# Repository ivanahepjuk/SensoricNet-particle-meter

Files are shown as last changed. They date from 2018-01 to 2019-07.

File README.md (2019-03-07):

# SensoricNet-particle-meter

Check sensoricnet.com website [here](https://www.sensoricnet.com).

*ALL FILES IN THIS SensoricNet-Particle-Meter REPOSITORY ARE PUBLISHED UNDER GNU GENERAL PUBLIC LICENSE Version 3, 29 June 2007*

This is repo for sensoricnet, project backed by Vodafone. Nb-Iot stuff.

# Firmware
Please go to the firmware folder

# Hardware
Please go to HW folder

# Backend
Plese go to TBD

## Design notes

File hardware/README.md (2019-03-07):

## Hardware plans

Created in KiCAD 5.0.2

##### SENSORICNET mother board version 1.0

* Core MCU STM32F072RBT6 (128kB memory)
* Communication by Quectel BC-95 NbIOT modem
* NanoSIM socket
* MOLEX PicoClasp connector for ALPHASENSE OPC-N2 (or OPC-N3) particle meter sensor
* GPS module Antennova M10578-A2, external antenna 
* ATECC508A secure element with internal cryptographic support for data validation, encrypting/decrypting, secure key storage
* RESET button, MODE button, three status LED's, one GPS FIX LED
* Prepared for 6V/500mA power source, variable connector (based on boxing)
* OLED 128x64 SSD1306 BW display
* Pin description added
* Added socket for BME280, it can be placed externally - improved accuracy 

OUTER SIDE:

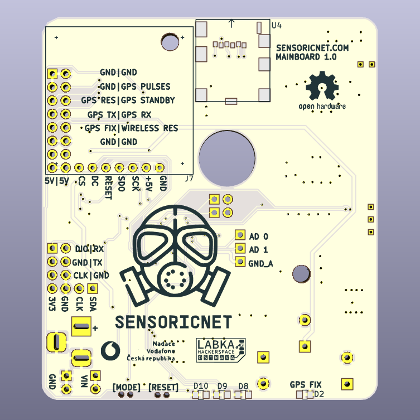
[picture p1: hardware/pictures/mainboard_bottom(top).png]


INNER SIDE:

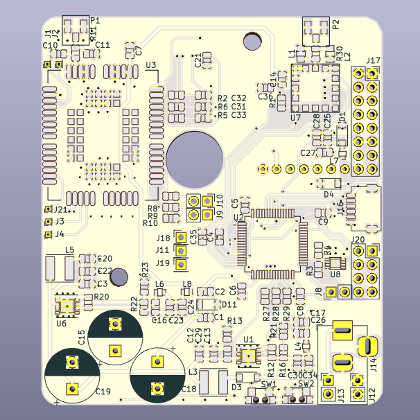
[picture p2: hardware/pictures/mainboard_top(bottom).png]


##### SENSORICNET LORAWAN shield

* Enhancement for SENSORICNET Motherboard
* Lorawan modem Microchip RN2483
* all pins form motherboard fit through this shield, possibility for adding another one

OUTER SIDE:

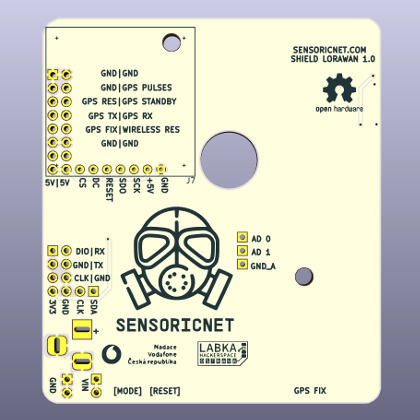
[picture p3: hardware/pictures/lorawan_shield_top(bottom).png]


INNER SIDE:

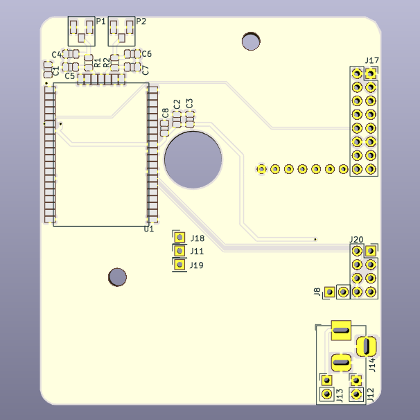
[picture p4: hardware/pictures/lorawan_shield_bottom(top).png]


##### SENSORICNET shield template
* Allows anybody to quickly develop own sensing shield for SENSORICNET
* Do you have an idea how to upgrade our sensor? Creating a shield sounds like a good way!

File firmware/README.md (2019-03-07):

# Install

##### Fedora:

(tested on Fedora release 26+)

Install openocd

```
sudo yum install openocd
sudo udevadm control -R
```

get the repo version of GNU Arm Embedded toolchains

```
sudo yum install arm-none-eabi-gdb arm-none-eabi-binutils-cs arm-none-eabi-gcc-cs arm-none-eabi-newlib
```

alternatively you can particular version of GNU Arm Embedded toolchains by

```
wget "https://armkeil.blob.core.windows.net/developer/Files/downloads/gnu-rm/6-2017q2/gcc-arm-none-eabi-6-2017-q2-update-linux.tar.bz2"
tar xvjf gcc-arm-none-eabi-6-2017-q2-update-linux.tar.bz2
```

and add path to .bash_profile

```
PATH=$PATH:/home/user/gcc-arm-none-eabi-6-2017-q2-update/bin
```

```
source .bash_profile
```

Get libopencm3

```
mkdir ~/git
cd ~/git
git clone https://github.com/libopencm3/libopencm3.git
```
checkout to used snapshot
```
git checkout f8aa36818ac57f92b68fbc7cd65767e782c5a3c8
```

and compile it

```
cd ~/git/libopencm3
make
```

Get the SensoricNet stuff

```
cd ~/git
git clone https://github.com/ivanahepjuk/SensoricNet-particle-meter.git
```

connect device, compile and flash the firmware

```
cd ~/git/SensoricNet-particle-meter/firmware/snpm/
make clean ; make flash
```

or probably the smarter way is using simple provisioning utility

- rename sensoricnet_lora_ids_example.csv file to sensoricnet_lora_ids.csv and modify it (add your data)
- compile and flash the stuff by running 

```
cd ~/git/SensoricNet-particle-meter/firmware/snpm/
./make_lora.sh <your_sensor_dev_id>
```

##### Debian 9

```
cd ~/git
git clone https://github.com/ivanahepjuk/SensoricNet-particle-meter.git
```

libopencm3 library:

```
cd SensoricNet.../firmware
git clone libopencm3
```

toolchain:

```

go to your home folder and make dedicated folder for arm toolchain:
mkdir ~/ARM_toolchain

download toolchain file into this ARM_toolchain folder:
https://developer.arm.com/open-source/gnu-toolchain/gnu-rm/downloads/6-2017-q2-update

extract it:
tar -xf <toolchain_file>

go to your home folder 
cd ~/

make a new file, name it .bash_profile
nano .bash_profile

and define path top your toolchain here (add this line with path to your toolchain files)
PATH=$PATH:/home/ia/ARM_toolchain/gcc-arm-none-eabi-6-2017-q2-update/bin

save it by pressing ctrl+x and then load it:
source ~/.bash_profile

test it by writing this into terminal:
arm-none-eabi-gcc --version

you should get this:
arm-none-eabi-gcc (GNU Tools for ARM Embedded Processors 6-2017-q2-update) 6.3.1 20170620 (release) [ARM/embedded-6-branch revision 249437]
Copyright (C) 2016 Free Software Foundation, Inc.
This is free software; see the source for copying conditions.  There is NO
warranty; not even for MERCHANTABILITY or FITNESS FOR A PARTICULAR PURPOSE.

////////////////////////////////////////////////////////////////
////////////////////////////////////////////////////////////////
////////////////////////////////////////////////////////////////

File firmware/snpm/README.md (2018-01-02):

# README

Put it into f0 example folder, libopencm3

## Board connections

| Port  | Function | Description |
| ----- | --- | --- |
| `PA9` | `(USART1_TX)`	| TTL serial output `(38400,8,N,1)` |

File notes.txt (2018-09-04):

Project layout
--------------

..
└── git
    ├── libopencm3
    └── SensoricNet-particle-meter

CPU used
--------

ARM STM32F072

GNU Arm Embedded Toolchain:
---------------------------

The GNU Arm Embedded toolchains are integrated and validated packages featuring the Arm Embedded GCC compiler,
libraries and other GNU tools necessary for bare-metal software development on devices based on the 
Arm Cortex-M and Cortex-R processors. 

  * https://developer.arm.com/open-source/gnu-toolchain/gnu-rm/downloads

Semihosting
-----------

Semihosting is a neat way to redirect STDOUT and STDIN from an embedded system to a debug window on a PC.
This allows you to output messages using printf functions without having to use/configure an RS232 or 
USB Virtual COM Port, and can also read input from the PC's keyboard via scanf functions.

  * http://www.keil.com/support/man/docs/armcc/armcc_pge1358787046598.htm
  * http://bgamari.github.io/posts/2014-10-31-semihosting.html
  * https://github.com/libopencm3/libopencm3-examples/tree/master/examples/stm32/l1/stm32l-discovery/usart-semihosting
  * https://github.com/rowol/stm32_discovery_arm_gcc/tree/master/semihosting
  * http://www.wolinlabs.com/blog/stm32f4.semihosting.html
  * http://www.openstm32.org/forumthread164#threadId798

vypadá to, že to funguje. Po přeložení a flashnutí je pořeba znovu spustit openocd

openocd -f /usr/share/openocd/scripts/interface/stlink-v2-1.cfg -f /usr/share/openocd/scripts/target/stm32f0x.cfg

a připojit se na port 4444

telnet localhost 4444

a tam zadat

arm semihosting enable
reset

určitě to půjde zautomatizovat v Makefile

POZOR! pokud se překládá s podporou semihosting (je to default), tak musí být připojený ST-LINK,
       jinak ta binárka nepoběží!!! Překlad bez semihostingu je potřeba explicitně provést pomocí

make ENABLE_SEMIHOSTING=0 flash

Alternativa je retargeting (imho presmerovani USART2 do debug konzole)

  * https://github.com/ChuckM/nucleo-retarget-example

GDB (GNU debuger)
-----------------

  * https://mcuoneclipse.com/2015/03/25/command-line-programming-and-debugging-with-gdb/
  * http://pandafruits.com/stm32_primer/stm32_primer_minimal.php

Hromadný deploying
------------------

Je potřeba si lokálně udržovat aktuální csv soubor s čidly (vzor je sensoricnet_lora_ids_example.csv).
Pak se kompilace provádí pomocí

cd ~/git/SensoricNet-particle-meter/firmware/snpm/
./make_lora.sh <your_sensor_dev_id>

////////////////////////////////
ukoly

Vyresit ID jednotlivych senzoru, tzn mozna HWID? Mozna funkci na zapis ID?

Benchmark gps?

Posilat vic zajimavych dat z quectelu. Posilat jako string, nevymyslet picoviny, easy to poslat.

Preruseni na usart, vyzkouset ale si neni jak? Jo je, ale jen pri up-linku.

//SPI connections:
GND
SCK
MOSI/SDI
MISO/SDO
SS
5V

GPS modul
---------

Sample input from module, USART2, baudrate 9600

$GPRMC,002911.261,V,,,,,0.00,0.00,060180,,,N*4C
$GPVTG,0.00,T,,M,0.00,N,0.00,K,N*32
$GPGGA,002912.261,,,,,0,0,,,M,,M,,*45
$GPGLL,,,,,002912.261,V,N*77
$GPGSA,A,1,,,,,,,,,,,,,,,*1E
$GPGSV,1,1,00*79

Popis:

$GPRMC

    Recommended minimum specific GPS/Transit data

    eg1. $GPRMC,081836,A,3751.65,S,14507.36,E,000.0,360.0,130998,011.3,E*62
    eg2. $GPRMC,225446,A,4916.45,N,12311.12,W,000.5,054.7,191194,020.3,E*68

           225446       Time of fix 22:54:46 UTC
           A            Navigation receiver warning A = OK, V = warning
           4916.45,N    Latitude 49 deg. 16.45 min North
           12311.12,W   Longitude 123 deg. 11.12 min West
           000.5        Speed over ground, Knots
           054.7        Course Made Good, True
           191194       Date of fix  19 November 1994
           020.3,E      Magnetic variation 20.3 deg East
           *68          mandatory checksum

    eg3. $GPRMC,220516,A,5133.82,N,00042.24,W,173.8,231.8,130694,004.2,W*70
            1    2    3    4    5     6    7    8      9     10  11 12

        1   220516     Time Stamp
        2   A          validity - A-ok, V-invalid
        3   5133.82    current Latitude
        4   N          North/South
        5   00042.24   current Longitude
        6   W          East/West
        7   173.8      Speed in knots
        8   231.8      True course
        9   130694     Date Stamp
        10  004.2      Variation
        11  W          East/West
        12  *70        checksum

    eg4. $GPRMC,hhmmss.ss,A,llll.ll,a,yyyyy.yy,a,x.x,x.x,ddmmyy,x.x,a*hh
    1    = UTC of position fix
    2    = Data status (V=navigation receiver warning)
    3    = Latitude of fix
    4    = N or S
    5    = Longitude of fix
    6    = E or W
    7    = Speed over ground in knots
    8    = Track made good in degrees True
    9    = UT date
    10   = Magnetic variation degrees (Easterly var. subtracts from true course)
    11   = E or W
    12   = Checksum

$GPVTG

    Track Made Good and Ground Speed.

    eg1. $GPVTG,360.0,T,348.7,M,000.0,N,000.0,K*43
    eg2. $GPVTG,054.7,T,034.4,M,005.5,N,010.2,K

           054.7,T      True track made good
           034.4,M      Magnetic track made good
           005.5,N      Ground speed, knots
           010.2,K      Ground speed, Kilometers per hour

    eg3. $GPVTG,t,T,,,s.ss,N,s.ss,K*hh
    1    = Track made good
    2    = Fixed text 'T' indicates that track made good is relative to true north
    3    = not used
    4    = not used
    5    = Speed over ground in knots
    6    = Fixed text 'N' indicates that speed over ground in in knots
    7    = Speed over ground in kilometers/hour
    8    = Fixed text 'K' indicates that speed over ground is in kilometers/hour
    9    = Checksum

    The actual track made good and speed relative to the ground.

    $--VTG,x.x,T,x.x,M,x.x,N,x.x,K
    x.x,T = Track, degrees True
    x.x,M = Track, degrees Magnetic
    x.x,N = Speed, knots
    x.x,K = Speed, Km/hr 

$GPGGA

    Global Positioning System Fix Data

    Name                      Example Data          Description
    Sentence Identifier               $GPGGA              Global Positioning System Fix Data
    Time                      170834              17:08:34 Z
    Latitude                    4124.8963, N          41d 24.8963' N or 41d 24' 54" N
    Longitude                     08151.6838, W           81d 51.6838' W or 81d 51' 41" W
    Fix Quality:
    - 0 = Invalid
    - 1 = GPS fix
    - 2 = DGPS fix                  1                 Data is from a GPS fix
    Number of Satellites              05                5 Satellites are in view
    Horizontal Dilution of Precision (HDOP)     1.5               Relative accuracy of horizontal position
    Altitude                    280.2, M            280.2 meters above mean sea level
    Height of geoid above WGS84 ellipsoid       -34.0, M            -34.0 meters
    Time since last DGPS update           blank               No last update
    DGPS reference station id             blank               No station id
    Checksum                    *75               Used by program to check for transmission errors

    Global Positioning System Fix Data. Time, position and fix related data for a GPS receiver.

    eg2. $--GGA,hhmmss.ss,llll.ll,a,yyyyy.yy,a,x,xx,x.x,x.x,M,x.x,M,x.x,xxxx

    hhmmss.ss = UTC of position
    llll.ll = latitude of position
    a = N or S
    yyyyy.yy = Longitude of position
    a = E or W
    x = GPS Quality indicator (0=no fix, 1=GPS fix, 2=Dif. GPS fix)
    xx = number of satellites in use
    x.x = horizontal dilution of precision
    x.x = Antenna altitude above mean-sea-level
    M = units of antenna altitude, meters
    x.x = Geoidal separation
    M = units of geoidal separation, meters
    x.x = Age of Differential GPS data (seconds)
    xxxx = Differential reference station ID

    eg3. $GPGGA,hhmmss.ss,llll.ll,a,yyyyy.yy,a,x,xx,x.x,x.x,M,x.x,M,x.x,xxxx*hh
    1    = UTC of Position
    2    = Latitude
    3    = N or S
    4    = Longitude
    5    = E or W
    6    = GPS quality indicator (0=invalid; 1=GPS fix; 2=Diff. GPS fix)
    7    = Number of satellites in use [not those in view]
    8    = Horizontal dilution of position
    9    = Antenna altitude above/below mean sea level (geoid)
    10   = Meters  (Antenna height unit)
    11   = Geoidal separation (Diff. between WGS-84 earth ellipsoid and
         mean sea level.  -=geoid is below WGS-84 ellipsoid)
    12   = Meters  (Units of geoidal separation)
    13   = Age in seconds since last update from diff. reference station
    14   = Diff. reference station ID#
    15   = Checksum

$GPGLL

    Geographic Position, Latitude / Longitude and time.

    eg1. $GPGLL,3751.65,S,14507.36,E*77
    eg2. $GPGLL,4916.45,N,12311.12,W,225444,A

           4916.46,N    Latitude 49 deg. 16.45 min. North
           12311.12,W   Longitude 123 deg. 11.12 min. West
           225444       Fix taken at 22:54:44 UTC
           A            Data valid

    eg3. $GPGLL,5133.81,N,00042.25,W*75
             1    2     3    4 5

        1    5133.81   Current latitude
        2    N         North/South
        3    00042.25  Current longitude
        4    W         East/West
        5    *75       checksum

    $--GLL,lll.ll,a,yyyyy.yy,a,hhmmss.ss,A llll.ll = Latitude of position

    a = N or S
    yyyyy.yy = Longitude of position
    a = E or W
    hhmmss.ss = UTC of position
    A = status: A = valid data 

$GPGSA

    GPS DOP and active satellites

    eg1. $GPGSA,A,3,,,,,,16,18,,22,24,,,3.6,2.1,2.2*3C
    eg2. $GPGSA,A,3,19,28,14,18,27,22,31,39,,,,,1.7,1.0,1.3*35

    1    = Mode:
         M=Manual, forced to operate in 2D or 3D
         A=Automatic, 3D/2D
    2    = Mode:
         1=Fix not available
         2=2D
         3=3D
    3-14 = IDs of SVs used in position fix (null for unused fields)
    15   = PDOP
    16   = HDOP
    17   = VDOP

$GPGSV

    GPS Satellites in view

    eg. $GPGSV,3,1,11,03,03,111,00,04,15,270,00,06,01,010,00,13,06,292,00*74
      $GPGSV,3,2,11,14,25,170,00,16,57,208,39,18,67,296,40,19,40,246,00*74
      $GPGSV,3,3,11,22,42,067,42,24,14,311,43,27,05,244,00,,,,*4D

      $GPGSV,1,1,13,02,02,213,,03,-3,000,,11,00,121,,14,13,172,05*67

    1    = Total number of messages of this type in this cycle
    2    = Message number
    3    = Total number of SVs in view
    4    = SV PRN number
    5    = Elevation in degrees, 90 maximum
    6    = Azimuth, degrees from true north, 000 to 359
    7    = SNR, 00-99 dB (null when not tracking)
    8-11 = Information about second SV, same as field 4-7
    12-15= Information about third SV, same as field 4-7
    16-19= Information about fourth SV, same as field 4-7

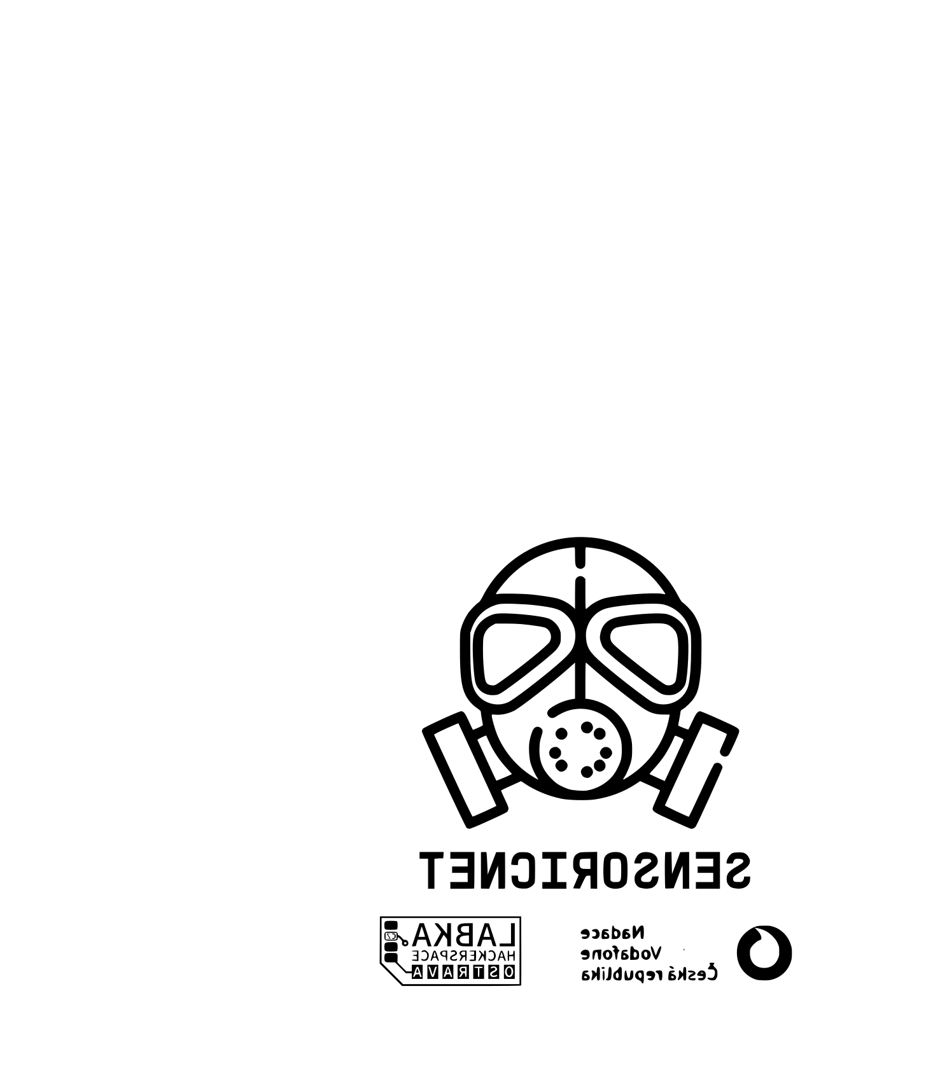
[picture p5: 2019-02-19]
hardware/footprints_and_modules/graphics/.svg2shenzhen-cache/images/F.Cu_g4502.png

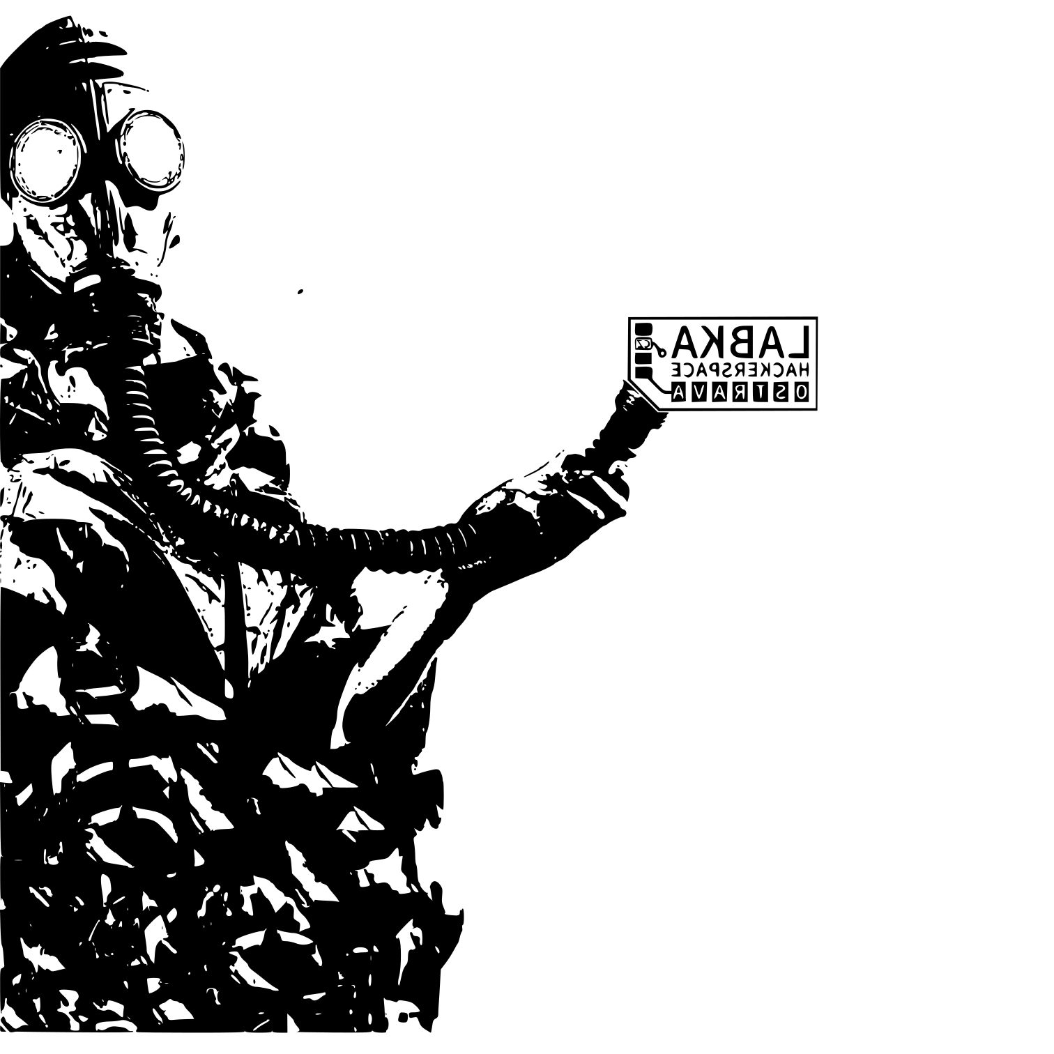
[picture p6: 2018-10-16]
hardware/footprints_and_modules/graphics/.svg2shenzhen-cache/images/F.Cu_g4633.png

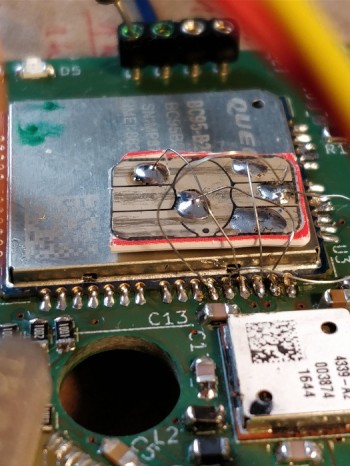
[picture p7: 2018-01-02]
Pictures/simka_resize.jpg

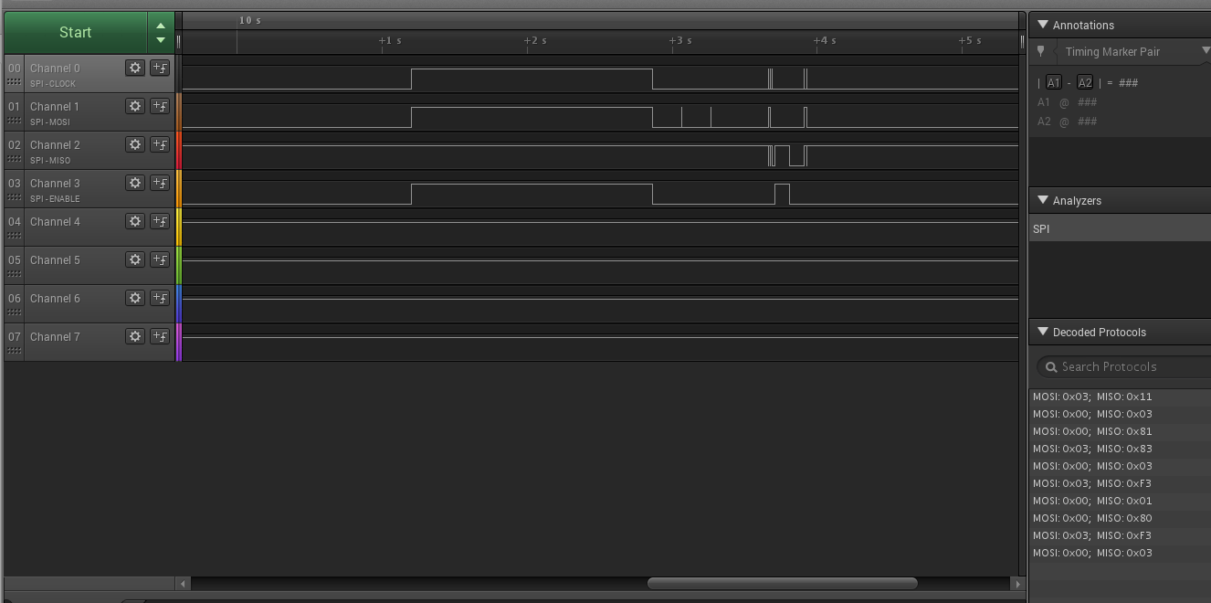
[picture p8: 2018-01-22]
firmware/communication_ok.png

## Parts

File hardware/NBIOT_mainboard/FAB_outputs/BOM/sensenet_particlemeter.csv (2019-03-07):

Id | Designator | Package | Quantity | Designation | Supplier and ref
1 | R9,R1,R8,R23,R27,R28,R29 | R_0805_2012Metric | 7 | 1k
2 | LOGO1 | PCB_artwork | 1 | LOGO
3 | U4 | nanosimmm | 1 | SIM
4 | U2 | TQFP-64_10x10mm_Pitch0.5mm | 1 | stm32f072
5 | J1,J2,J3,J4,J21 | Pin_Header_Straight_1x01_Pitch1.00mm | 5 | CONN_01X01
6 | J5,J6 | MountingHole_3.2mm_M3_DIN965 | 2 | CONN_01X01
7 | L2,L1 | SMD_0805 | 2 | DNP
8 | U3 | quectel_BC95 | 1 | QUECTEL_BC95
9 | U7 | M10578 | 1 | M10578-A2
10 | J11,J18,J19 | Pin_Header_Straight_1x01_Pitch2.54mm | 3 | CONN_01X01
11 | L4,L6,L7,L8 | R_0603 | 4 | FBMH1608HL601-T
12 | D2,D10 | SMD_0805_bottom | 2 | LED GREEN
13 | D8 | SMD_0805_bottom | 1 | LED RED
14 | D9 | SMD_0805_bottom | 1 | LED YELLOW
15 | P1,P2 | Antenna_conn | 2 | SMA_mini
16 | SW1,SW2 | edge_switch | 2 | SW_DPST
17 | C17,C25,C1,C4,C5,C6,C7,C8,C9,C12,C20,C21,C23,C36 | C_0805_2012Metric | 14 | 100n
18 | R30,R11 | R_0805_2012Metric | 2 | 0R
19 | C28,C2 | C_0805_2012Metric | 2 | 22p
20 | C26,C27,C29,C22,C24,C35 | C_0805_2012Metric | 6 | 1n
21 | C30,C16,C34 | C_0805_2012Metric | 3 | 47u
22 | U1,U6 | DFN-8-1EP_4x4mm_P0.8mm_EP2.39x2.21mm | 2 | NCP59152
23 | D1,D4 | D_SOD-123 | 2 | PTVS3V3S1UR,115
24 | C10,C11 | C_0805_2012Metric | 2 | DNP
25 | C13,C3 | C_0805_2012Metric | 2 | 22u
26 | C14 | C_0805_2012Metric | 1 | 2,2u
27 | J17 | PinSocket_2x08_P2.54mm_Vertical | 1 | Conn_02x08_Odd_Even
28 | J20 | PinSocket_2x04_P2.54mm_Vertical | 1 | Conn_02x04_Odd_Even
29 | R3,R4 | R_0805_2012Metric | 2 | 4k7
30 | U8 | DFN-8-1EP_3x2mm_P0.5mm_EP1.75x1.45mm | 1 | ATECC508A
31 | R10 | R_0805_2012Metric | 1 | 10k
32 | R12,R13,R20 | R_0805_2012Metric | 3 | 100k
33 | R16 | R_0805_2012Metric | 1 | 3k3
34 | R21 | R_0805_2012Metric | 1 | 1k1
35 | R22 | R_0805_2012Metric | 1 | 1k6
36 | C31,C32,C33 | C_0805_2012Metric | 3 | 33p
37 | R2,R5,R6 | R_0805_2012Metric | 3 | 22R
38 | D3 | D_SOD-123 | 1 | D_Schottky_ss14
39 | D11 | D_SOD-123 | 1 | SM2T3V3A
40 | J16 | pico_clasp_6_horizontal | 1 | Conn_01x06_Female
41 | L3 | L_Taiyo-Yuden_NR-50xx | 1 | 39uH
42 | L5 | L_Taiyo-Yuden_NR-50xx | 1 | 41uH
43 | J8,J9,J10 | PinHeader_1x02_P2.54mm_Vertical | 3 | Conn_02x01
44 | C18 | CP_Radial_D10.0mm_P5.00mm | 1 | 470uF
45 | C19,C15 | CP_Radial_D10.0mm_P5.00mm | 2 | 470u
46 | J7 | OLED | 1 | Conn_01x07_Female
47 | LOGO2 | OSHW-Logo2_9.8x8mm_BackSilkScreen | 1 | LOGO
48 | J12 | BarrelJack_Horizontal | 1 | Barrel_Jack_Switch
49 | J13,J14 | PinHeader_1x02_P2.54mm_Vertical | 2 | Conn_01x02_Female

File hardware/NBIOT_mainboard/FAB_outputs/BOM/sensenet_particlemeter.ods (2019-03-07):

Id | Designator | Package | Quantity | Designation | Populate | Just order | Discuss | Notes | Links
1 | R9,R1,R8,R23,R27,R28,R29 | R_0805_2012Metric | 7 | 1k | yes
2 | LOGO1 | PCB_artwork | 1 | LOGO | no
3 | U4 | nanosimmm | 1 | SIM | yes |  |  |  | https://www.tme.eu/cz/details/mx-504520-0691_c/konektory-ke-kartam/molex/504520-0691/
4 | U2 | TQFP-64_10x10mm_Pitch0.5mm | 1 | stm32f072 | yes |  |  | STM32F072RBT6 | https://www.arrow.com/en/products/stm32f072rbt6/stmicroelectronics
5 | J1,J2,J3,J4,J21 | Pin_Header_Straight_1x01_Pitch1.00mm | 5 | CONN_01X01 | no | yes*
6 | J5,J6 | MountingHole_3.2mm_M3_DIN965 | 2 | CONN_01X01 | no
7 | L2,L1 | SMD_0805 | 2 | DNP | no
8 | U3 | quectel_BC95 | 1 | QUECTEL_BC95 | yes |  |  |  | https://www.soselectronic.cz/products/quectel/bc95-b20-bc95-b20hb-02-std-234632
9 | U7 | M10578 | 1 | M10578-A2 | yes |  |  |  | https://www.arrow.com/en/products/m10578-a2/antenova
10 | J11,J18,J19 | Pin_Header_Straight_1x01_Pitch2.54mm | 3 | CONN_01X01 |  | yes*
11 | L4,L6,L7,L8 | R_0603 | 4 | FBMH1608HL601-T | yes |  |  |  | https://www.arrow.com/en/products/fbmh1608hl601-t/taiyo-yuden
12 | D2,D10 | SMD_0805_bottom | 2 | LED GREEN | yes |  | x | please choose
13 | D8 | SMD_0805_bottom | 1 | LED RED | yes |  | x | please choose
14 | D9 | SMD_0805_bottom | 1 | LED YELLOW | yes |  | x | please choose
15 | P1,P2 | Antenna_conn | 2 | SMA_mini | yes |  | x |  | ???
16 | SW1,SW2 | edge_switch | 2 | SW_DPST | yes |  | x |  | ???
17 | C17,C25,C1,C4,C5,C6,C7,C8,C9,C12,C20,C21,C23,C36 | C_0805_2012Metric | 14 | 100n | yes |  |  |  | 6.3V
18 | R30,R11 | R_0805_2012Metric | 2 | 0R | yes
19 | C28,C2 | C_0805_2012Metric | 2 | 22p | yes |  |  |  | 6.3V
20 | C26,C27,C29,C22,C24,C35 | C_0805_2012Metric | 6 | 1n | yes |  |  |  | 6.3V
21 | C30,C16,C34 | C_0805_2012Metric | 3 | 47u | yes |  |  |  | 6.3V
22 | U1,U6 | DFN-8-1EP_4x4mm_P0.8mm_EP2.39x2.21mm | 2 | NCP59152 | yes |  |  | NCP59152MNADJTYG
23 | D1,D4 | D_SOD-123 | 2 | PTVS3V3S1UR,115 | yes |  |  |  | https://www.arrow.com/en/products/ptvs3v3s1ur115/nexperia
24 | C10,C11 | C_0805_2012Metric | 2 | DNP | no
25 | C13,C3 | C_0805_2012Metric | 2 | 22u | yes |  |  |  | 6.3V
26 | C14 | C_0805_2012Metric | 1 | 2,2u | yes |  |  |  | 6.3V
27 | J17 | PinSocket_2x08_P2.54mm_Vertical | 1 | Conn_02x08_Odd_Even |  | yes*
28 | J20 | PinSocket_2x04_P2.54mm_Vertical | 1 | Conn_02x04_Odd_Even |  | yes*
29 | R3,R4 | R_0805_2012Metric | 2 | 4k7 | yes
30 | U8 | DFN-8-1EP_3x2mm_P0.5mm_EP1.75x1.45mm | 1 | ATECC508A | yes |  |  |  | https://www.arrow.com/en/products/atecc608a-mahda-s/microchip-technology
31 | R10 | R_0805_2012Metric | 1 | 10k | yes
32 | R12,R13,R20 | R_0805_2012Metric | 3 | 100k | yes
33 | R16 | R_0805_2012Metric | 1 | 3k3 | yes
34 | R21 | R_0805_2012Metric | 1 | 1k1 | yes
35 | R22 | R_0805_2012Metric | 1 | 1k6 | yes
36 | C31,C32,C33 | C_0805_2012Metric | 3 | 33p | yes |  |  | 6.3V
37 | R2,R5,R6 | R_0805_2012Metric | 3 | 22R | yes
38 | D3 | D_SOD-123 | 1 | D_Schottky_ss14 | yes |  |  |  | https://www.arrow.com/en/products/pmeg4010eh115/nexperia
39 | D11 | D_SOD-123 | 1 | SM2T3V3A | yes |  |  |  | https://www.arrow.com/en/products/sm2t3v3a/stmicroelectronics
40 | J16 | pico_clasp_6_horizontal | 1 | Conn_01x06_Female | yes |  |  |  | https://www.arrow.com/en/products/5015680607/molex
41 | L3 | L_Taiyo-Yuden_NR-50xx | 1 | 39uH
42 | L5 | L_Taiyo-Yuden_NR-50xx | 1 | 41uH
43 | J8,J9,J10 | PinHeader_1x02_P2.54mm_Vertical | 3 | Conn_02x01 |  | yes*
44 | C18 | CP_Radial_D10.0mm_P5.00mm | 1 | 470uF | no | yes
45 | C19,C15 | CP_Radial_D10.0mm_P5.00mm | 2 | 470u | no | yes |  |  | https://www.arrow.com/en/products/ece-a0jn471x/panasonic
46 | J7 | OLED | 1 | Conn_01x07_Female | no
47 | LOGO2 | OSHW-Logo2_9.8x8mm_BackSilkScreen | 1 | LOGO | no
48 | J12 | BarrelJack_Horizontal | 1 | Barrel_Jack_Switch | yes |  | x |  | ???
49 | J13,J14 | PinHeader_1x02_P2.54mm_Vertical | 2 | Conn_01x02_Female |  | yes*
 |  |  | Another orders for each board:
 |  | Part | amount per one board: | note | Link
 |  | lte antenna check | 1 |  | https://www.arrow.com/en/products/srfl026-150/antenova
 |  | GPS antenna | 1 |  | https://www.arrow.com/en/products/sr4g031-150/antenova
 |  | wire molex | 1 | Connecting wire MOLEX s.n. 15133-0601 [100mm] | https://cz.mouser.com/ProductDetail/Molex/15133-0601?qs=jFK2DQXLaBwzzgKQ6LYJrw%3D%3D
 |  | distancni sloupek M3 | 2 | vnitrni zavit 4mm, vyska sloupku 5mm, vnejsi zavit 5mm
 |  | distancni sloupek M3 | 2 | vnitrni zavit 4mm, vyska sloupku 12mm, vnejsi zavit 5mm

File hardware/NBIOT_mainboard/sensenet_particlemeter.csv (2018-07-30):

Id | Designator | Package | Quantity | Designation | Supplier and ref
1 | P4 | USB_Micro-B | 1 | USB_B
2 | U2 | TQFP-64_10x10mm_Pitch0.5mm | 1 | stm32f072
3 | BT1 | BAT-CR2032_bottom | 1 | Battery_Cell
4 | C3,C6,C9,C13,C4,C8 | SMD_0805 | 6 | C
5 | C5,C7,C21,C25 | SMD_0805 | 4 | 100n
6 | C10,C11 | SMD_0805 | 2 | NC
7 | C14 | SMD_0805 | 1 | 2,2u
8 | C23 | SMD_0805 | 1 | 10u
9 | C24 | SMD_0805 | 1 | 220n
10 | D1 | D_SOD-123 | 1 | D_Schottky
11 | D2,D4,D7,D8,D9,D10 | SMD_0805 | 6 | LED
12 | D3 | D_SOD-123 | 1 | D_Schottky_ss14
13 | J1,J2,J3,J4,J21 | Pin_Header_Straight_1x01_Pitch1.00mm | 5 | CONN_01X01
14 | J5,J6 | MountingHole_3.2mm_M3_DIN965 | 2 | CONN_01X01
15 | J13 | BARREL_JACK | 1 | BARREL_JACK
16 | L2,L1 | SMD_0805 | 2 | L
17 | P1,P2 | Antenna_conn | 2 | SMA_mini
18 | R1,R17,R18,R27,R28,R29 | SMD_0805 | 6 | R
19 | R2,R4,R5 | SMD_0805 | 3 | 4.7k
20 | R3,R26 | SMD_0805 | 2 | 5k6
21 | R6 | SMD_0805 | 1 | 22k
22 | R7,R10,R14 | SMD_0805 | 3 | 10k
23 | R8,R9 | SMD_0805 | 2 | 1k
24 | U3 | quectel_BC95 | 1 | QUECTEL_BC95
25 | U7 | M10578 | 1 | M10578-A2
26 | U10 | BME280 | 1 | bme280_barebone
27 | J11,J17,J18,J19,J20 | Pin_Header_Straight_1x01_Pitch2.54mm | 5 | CONN_01X01
28 | SJ16 | solder_jumper | 1 | solder_jumper
29 | Y1 | Crystal_SMD_5032-2pin_5.0x3.2mm | 1 | 8MHz
30 | C1,C2 | SMD_0805 | 2 | 4.3p
31 | C12 | SMD_0805 | 1 | 510pF
32 | C15 | SMD_0805 | 1 | 1u
33 | R12,R19 | SMD_0805 | 2 | 0R33
34 | R13,R20,R21,R24 | SMD_0805 | 4 | tbd
35 | R15 | SMD_0805 | 1 | 27k
36 | R16 | SMD_0805 | 1 | 9.1k
37 | U1,U6 | SOIC-8_3.9x4.9mm_Pitch1.27mm | 2 | MC33063
38 | U5 | SOT-23-5 | 1 | CAT24C02
39 | Q1 | SOT-23 | 1 | Q_NMOS_GSD
40 | U4 | nanosimmm | 1 | SIM
41 | R11 | SMD_0805 | 1 | 0R
42 | C16 | SMD_0805 | 1 | 352pF
43 | R22 | SMD_0805 | 1 | 18k
44 | R23 | SMD_0805 | 1 | 11k
45 | R25,R30 | SMD_0805 | 2 | 0R1
46 | L3 | Inductor_Taiyo-Yuden_NR-50xx | 1 | 39uH
47 | L4,L6 | SMD_0805 | 2 | 1uH
48 | L5 | Inductor_Taiyo-Yuden_NR-50xx | 1 | 41uH
49 | D5,D6 | SOD-123 | 2 | 1N5819
50 | C17,C19 | C_Radial_D10_L16_P5_bottom | 2 | 1000u
51 | C18 | C_Radial_D6.3_L11.2_P2.5_bottom | 1 | 470uF
52 | P3 | Pin_Header_Straight_2x12 | 1 | CONN_02X12
53 | SW2 | DIP-6_W7.62mm | 1 | SW_DIP_x03
54 | SW1,SW3 | edge_switch | 2 | SW_DPST
55 |  | drawing | 1

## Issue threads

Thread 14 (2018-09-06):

Zvýšit přesnost přenášených GPS souřadnic

dron23, 2018-09-06:
GPS souřadnice jsou enkodováním do cayenne lpp oříznuty na 4 desetinná místa. GPS ale vrací 6. Workaround je naznačen v kapitole "4.3. Full scale GPS Payload" v http://community.mydevices.com/t/cayenne-lpp-2-0/7510. Oprava se bude muset ud2lat i v dron23/SensoricNet-udp#2.

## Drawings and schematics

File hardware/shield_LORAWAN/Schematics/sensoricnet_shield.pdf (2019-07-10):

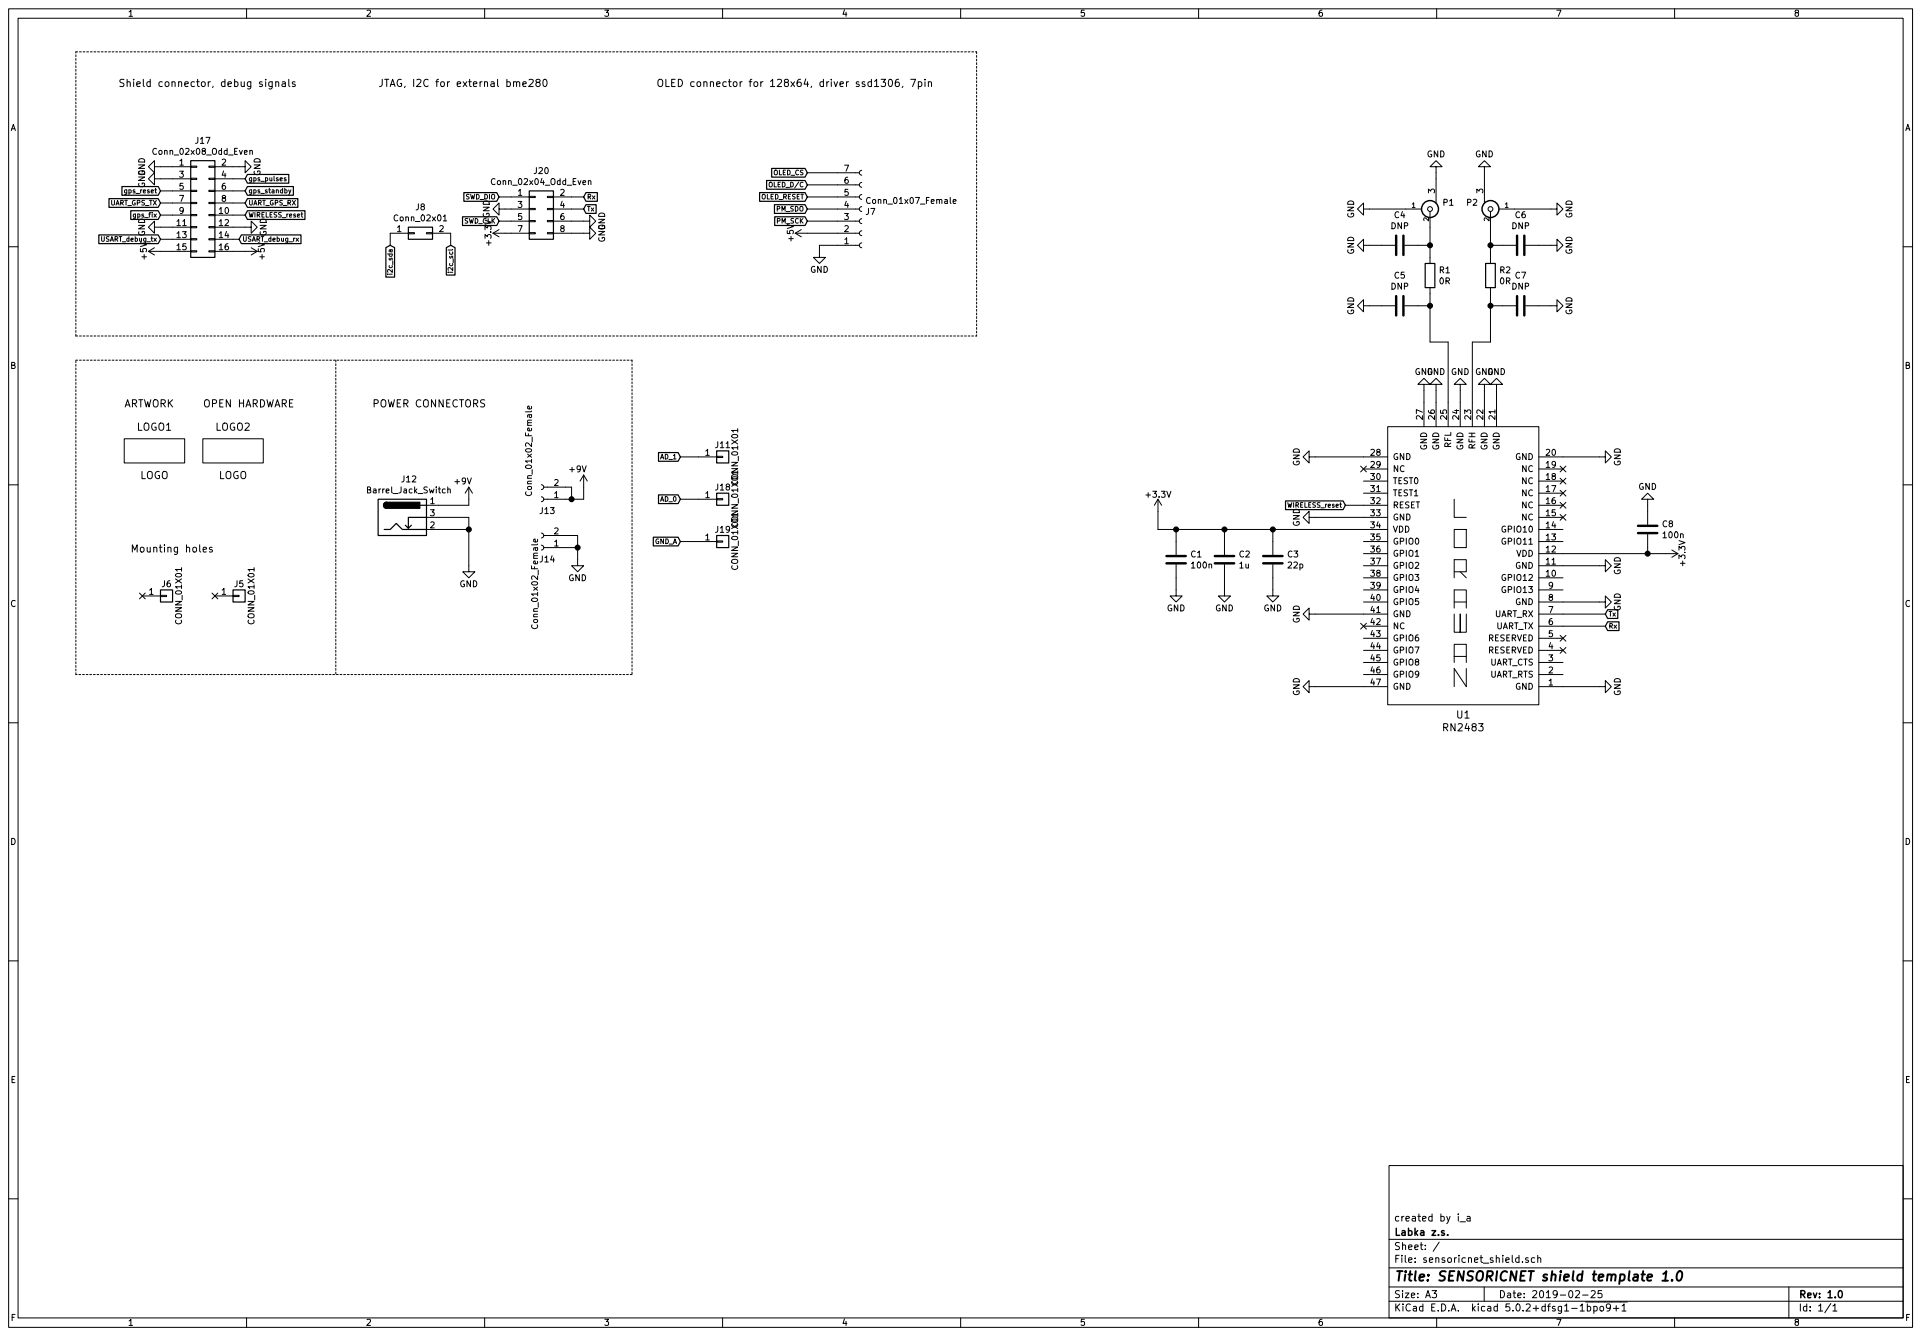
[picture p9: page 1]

2 3 P2 GND GND GND GND GNDGND GND GNDGND GND GND GND GND +3.3V WIRELESS_reset Rx Tx

C4 DNP C5 DNP GND GND

File: sensoricnet_shield.sch Sheet: / Labka z.s. created by i_a

Id: 1/1 Title: SENSORICNET shield template 1.0

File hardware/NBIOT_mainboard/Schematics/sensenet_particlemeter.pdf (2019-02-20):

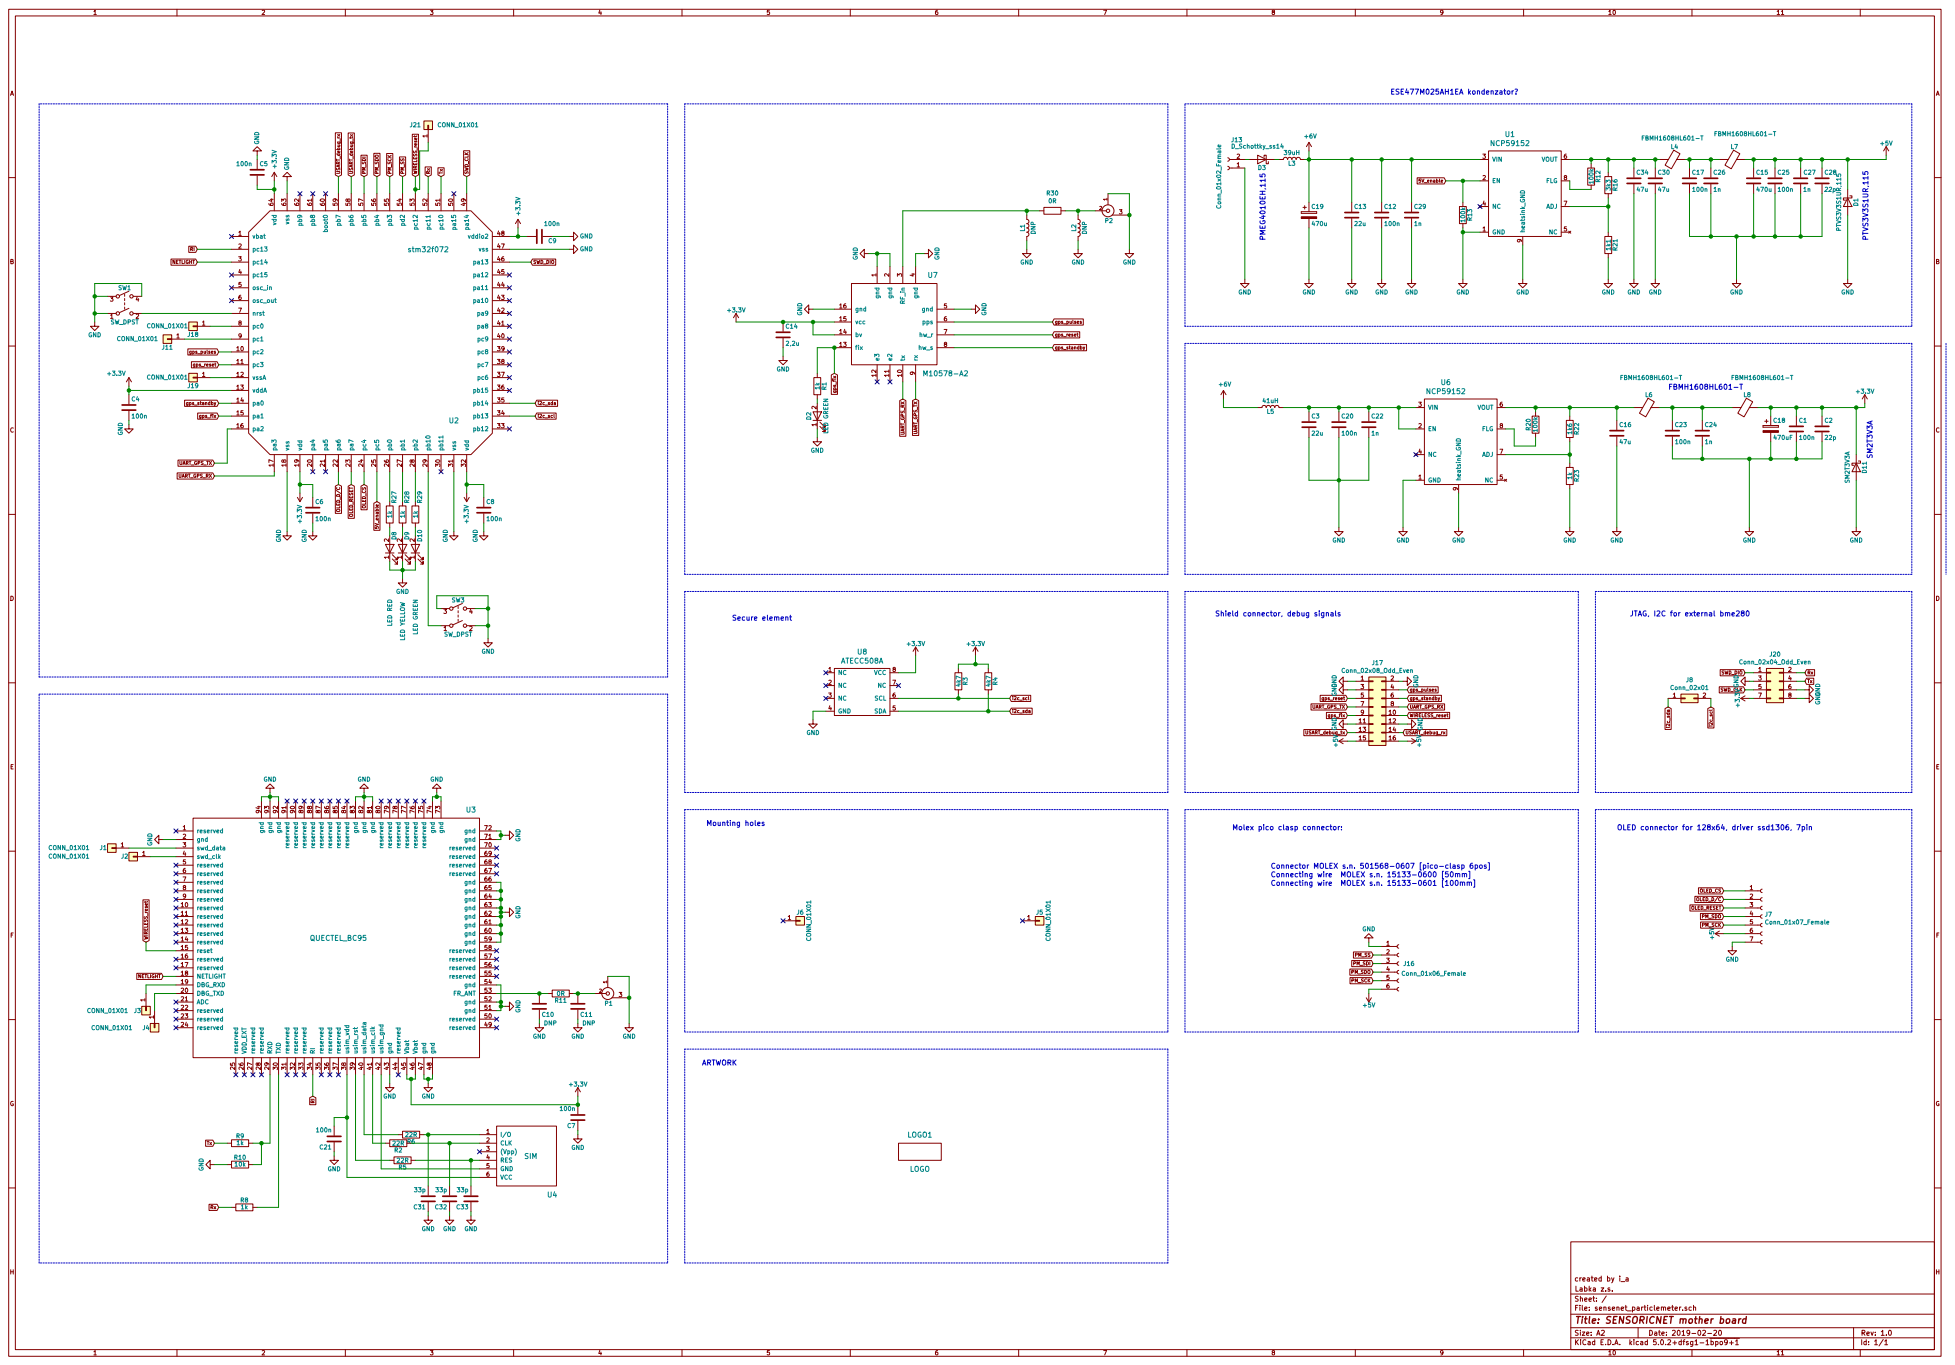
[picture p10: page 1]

1 2 D2 LED GREEN 1kR1 GND GND GND GND GND

vcc 15
fix 13
1n GND Connector MOLEX s.n. 501568-0607 [pico-clasp 6pos]

File: sensenet_particlemeter.sch Sheet: / Labka z.s. created by i_a

Id: 1/1 Title: SENSORICNET mother board

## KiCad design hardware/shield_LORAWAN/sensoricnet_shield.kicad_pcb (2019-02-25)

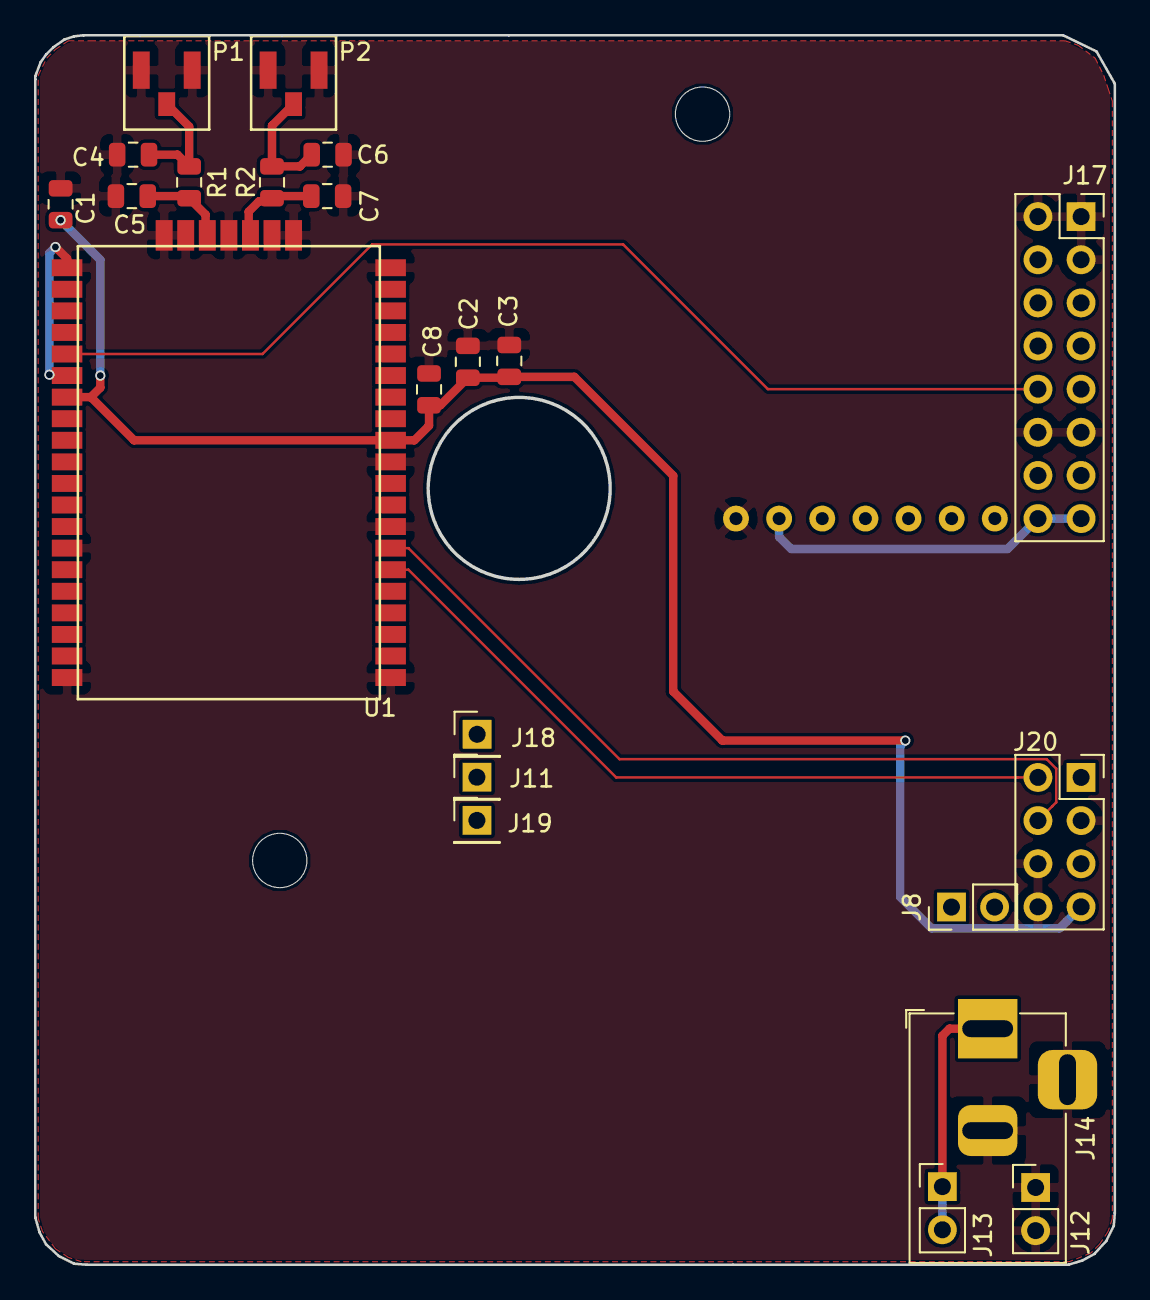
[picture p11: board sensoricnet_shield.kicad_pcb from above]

Board: 2 copper layers, 63.6 x 72.4 mm, 27 parts (0 on the bottom side), 11 nets.

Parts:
C1, C8: 100n; C_0805_2012Metric
C2: 1u; C_0805_2012Metric
C3: 22p; C_0805_2012Metric
C4, C5, C6, C7: DNP; C_0805_2012Metric
J5, J6: CONN_01X01; MountingHole_3.2mm_M3_DIN965
J7: Conn_01x07_Female; OLED
J8: Conn_02x01; PinHeader_1x02_P2.54mm_Vertical
J11, J18, J19: CONN_01X01; PinHeader_1x01_P2.54mm_Vertical
J12: Barrel_Jack_Switch; BarrelJack_Horizontal
J13, J14: Conn_01x02_Female; PinHeader_1x02_P2.54mm_Vertical
J17: Conn_02x08_Odd_Even; PinSocket_2x08_P2.54mm_Vertical
J20: Conn_02x04_Odd_Even; PinSocket_2x04_P2.54mm_Vertical
LOGO1: LOGO; PCB_artwork
LOGO2: LOGO; OSHW-Logo2_9.8x8mm_BackSilkScreen
P1, P2: SMA_mini; Antenna_conn
R1, R2: 0R; R_0805_2012Metric
U1: RN2483; RN2483_top

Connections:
+3V3: C1.1, C2.1, C3.1, C8.2, J20.7, U1.12, U1.34
+5V: J7.2, J17.15, J17.16
+9V: J12.1, J13.1, J13.2
GND: C1.2, C2.2, C3.2, C4.1, C5.1, C6.1, C7.1, C8.1, J7.1, J12.2, J12.3, J14.1, J14.2, J17.1, J17.2, J17.3, J17.11, J17.12, J20.3, J20.6, J20.8, P1.1, P1.3, P2.1, P2.3, U1.1, U1.8, U1.11, U1.20, U1.21, U1.22, U1.24, U1.26, U1.27, U1.28, U1.33, U1.41, U1.47
unnamed: C4.2, P1.2, R1.1
unnamed: C5.2, R1.2, U1.25
unnamed: C6.2, P2.2, R2.1
unnamed: C7.2, R2.2, U1.23
Rx: J20.2, U1.6
Tx: J20.4, U1.7
WIRELESS_reset: J17.10, U1.32

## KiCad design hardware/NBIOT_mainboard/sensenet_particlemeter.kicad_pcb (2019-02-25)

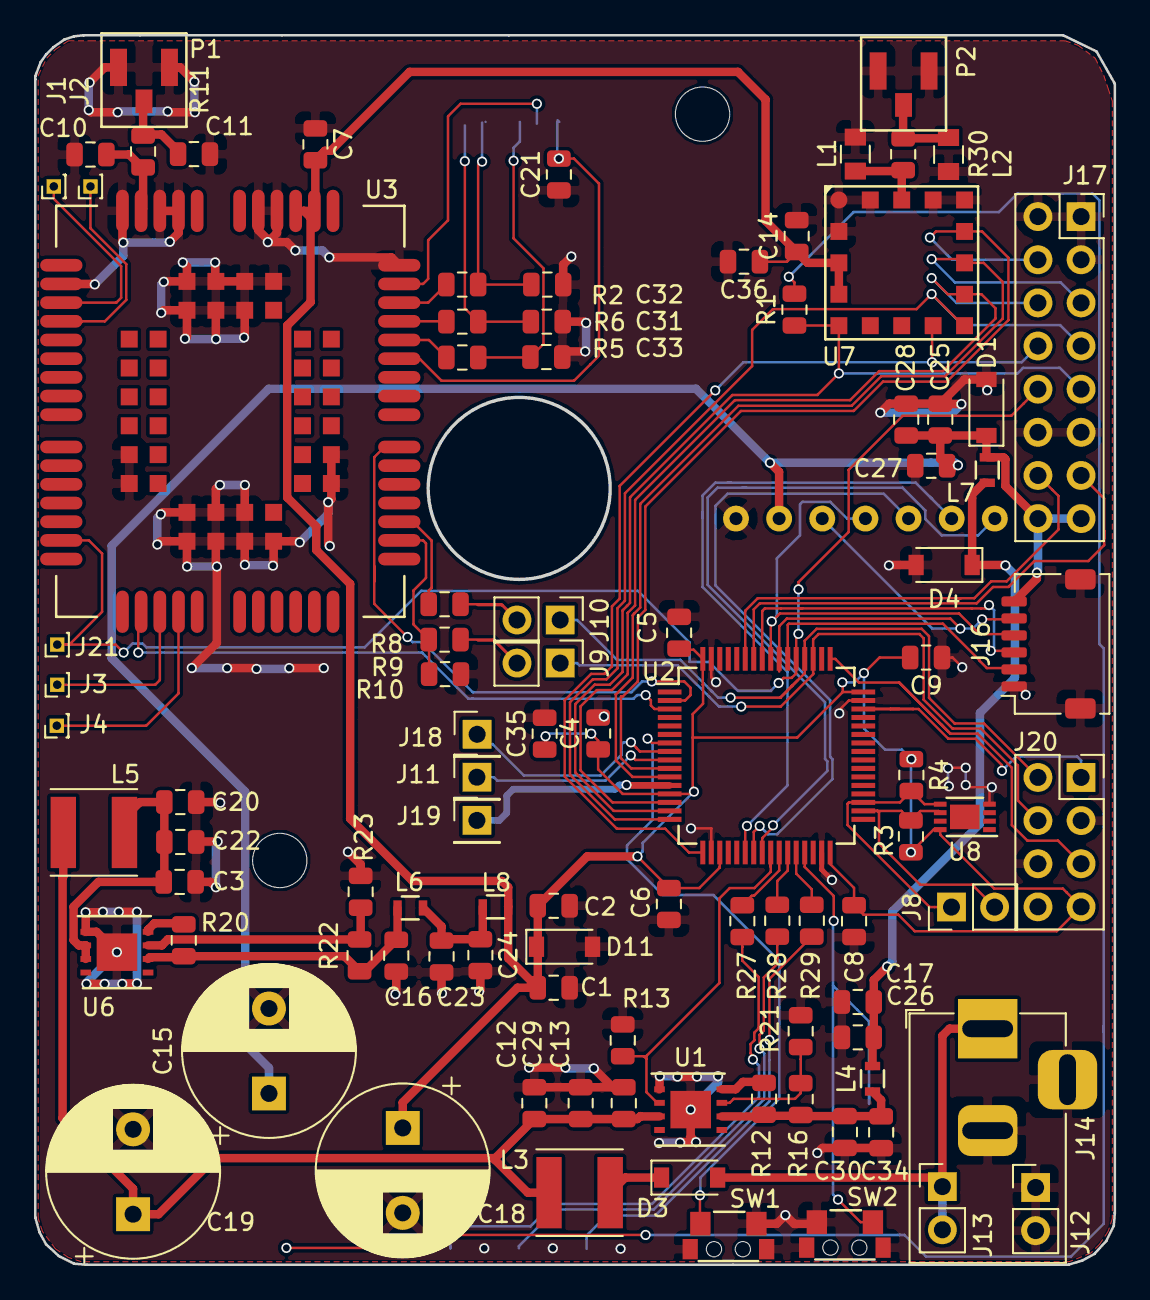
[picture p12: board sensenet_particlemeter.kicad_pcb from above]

Board: 2 copper layers, 63.6 x 72.4 mm, 106 parts (0 on the bottom side), 72 nets.

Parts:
C1, C4, C5, C6, C7, C8, C9, C12, C17, C20, C21, C23, C25, C36: 100n; C_0805_2012Metric
C2, C28: 22p; C_0805_2012Metric
C3, C13: 22u; C_0805_2012Metric
C10, C11: DNP; C_0805_2012Metric
C14: 2,2u; C_0805_2012Metric
C15, C19: 470u; CP_Radial_D10.0mm_P5.00mm
C16, C30, C34: 47u; C_0805_2012Metric
C18: 470uF; CP_Radial_D10.0mm_P5.00mm
C22, C24, C26, C27, C29, C35: 1n; C_0805_2012Metric
C31, C32, C33: 33p; C_0805_2012Metric
D1, D4: PTVS3V3S1UR,115; D_SOD-123
D2, D10: LED GREEN; SMD_0805_bottom
D3: D_Schottky_ss14; D_SOD-123
D8: LED RED; SMD_0805_bottom
D9: LED YELLOW; SMD_0805_bottom
D11: SM2T3V3A; D_SOD-123
J1, J2, J3, J4, J21: CONN_01X01; Pin_Header_Straight_1x01_Pitch1.00mm
J5, J6: CONN_01X01; MountingHole_3.2mm_M3_DIN965
J7: Conn_01x07_Female; OLED
J8, J9, J10: Conn_02x01; PinHeader_1x02_P2.54mm_Vertical
J11, J18, J19: CONN_01X01; Pin_Header_Straight_1x01_Pitch2.54mm
J12: Barrel_Jack_Switch; BarrelJack_Horizontal
J13, J14: Conn_01x02_Female; PinHeader_1x02_P2.54mm_Vertical
J16: Conn_01x06_Female; pico_clasp_6_horizontal
J17: Conn_02x08_Odd_Even; PinSocket_2x08_P2.54mm_Vertical
J20: Conn_02x04_Odd_Even; PinSocket_2x04_P2.54mm_Vertical
L1, L2: DNP; SMD_0805
L3: 39uH; L_Taiyo-Yuden_NR-50xx
L4, L6, L7, L8: FBMH1608HL601-T; R_0603
L5: 41uH; L_Taiyo-Yuden_NR-50xx
LOGO1: LOGO; PCB_artwork
LOGO2: LOGO; OSHW-Logo2_9.8x8mm_BackSilkScreen
P1, P2: SMA_mini; Antenna_conn
R1, R8, R9, R23, R27, R28, R29: 1k; R_0805_2012Metric
R2, R5, R6: 22R; R_0805_2012Metric
R3, R4: 4k7; R_0805_2012Metric
R10: 10k; R_0805_2012Metric
R11, R30: 0R; R_0805_2012Metric
R12, R13, R20: 100k; R_0805_2012Metric
R16: 3k3; R_0805_2012Metric
R21: 1k1; R_0805_2012Metric
R22: 1k6; R_0805_2012Metric
SW1, SW2: SW_DPST; edge_switch
U1, U6: NCP59152; DFN-8-1EP_4x4mm_P0.8mm_EP2.39x2.21mm
U2: stm32f072; TQFP-64_10x10mm_Pitch0.5mm
U3: QUECTEL_BC95; quectel_BC95
U4: SIM; nanosimmm
U7: M10578-A2; M10578
U8: ATECC508A; DFN-8-1EP_3x2mm_P0.5mm_EP1.75x1.45mm

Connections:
5V_enable: R13.1, U1.2, U2.25
+3V3: C1.1, C2.1, C4.1, C5.2, C6.1, C7.2, C8.1, C9.2, C14.1, C18.1, C35.1, C36.1, D11.1, J20.7, L8.1, R3.1, R4.1, U2.13, U2.19, U2.32, U2.48, U2.64, U3.45, U3.46, U7.14, U7.15, U8.8
+5V: C15.1, C25.1, C27.1, C28.1, D1.1, J7.2, J16.6, J17.15, J17.16, L7.1
+6V: C12.1, C13.1, C19.1, C29.1, L3.2, L5.1, U1.3
+9V: D3.2, J12.1, J13.1, J13.2
GND: C1.2, C2.2, C3.2, C4.2, C5.1, C6.2, C7.1, C8.2, C9.1, C10.1, C11.1, C12.2, C13.2, C14.2, C15.2, C16.2, C17.2, C18.2, C19.2, C20.2, C21.1, C22.2, C23.2, C24.2, C25.2, C26.2, C27.2, C28.2, C29.2, C30.2, C31.1, C32.1, C33.1, C34.2, C35.2, C36.2, D1.2, D2.1, D4.2, D8.1, D9.1, D10.1, D11.2, J7.1, J12.2, J12.3, J14.1, J14.2, J16.1, J17.1, J17.2, J17.3, J17.11, J17.12, J20.3, J20.6, J20.8, L1.2, L2.2, P1.1, P1.3, P2.1, P2.3, R10.1, R13.2, R21.2, R23.2, SW1.1, SW1.3, SW1.4, SW2.2, SW2.3, SW2.4, U1.1, U1.9, U2.18, U2.31, U2.47, U2.63, U3.2, U3.43, U3.47, U3.48, U3.51, U3.52, U3.54, U3.59, U3.60, U3.61, U3.62, U3.63, U3.64, U3.65, U3.66, U3.71, U3.72, U3.73, U3.74, U3.81, U3.82, U3.83, U3.92, U3.93, U3.94, U6.1, U6.9, U7.1, U7.2, U7.4, U7.5, U7.16, U8.4
NETLIGHT: U2.3, U3.18
unnamed: C10.2, R11.2, U3.53
unnamed: C11.2, P1.2, R11.1
unnamed: C16.1, L6.2, R20.2, R22.1, U6.6
unnamed: C17.1, C26.1, D4.1, L4.1, L7.2
unnamed: C3.1, C20.1, C22.1, L5.2, U6.2, U6.3
unnamed: C21.2, U3.38, U4.6
unnamed: C23.1, C24.1, L6.1, L8.2
unnamed: C30.1, C34.1, L4.2, R12.1, R16.1, U1.6
unnamed: C31.2, R6.1, U4.1
unnamed: C32.2, R2.1, U4.2
unnamed: C33.2, R5.1, U4.4
unnamed: D2.2, R1.2
unnamed: D3.1, L3.1
unnamed: D8.2, R27.2
unnamed: D9.2, R28.2
unnamed: D10.2, R29.2
unnamed: J1.1, U3.3
unnamed: J2.1, U3.4
unnamed: J3.1, U3.19
unnamed: J4.1, U3.20
unnamed: J9.2, R9.1
unnamed: J10.2, R8.1
unnamed: J11.1, U2.9
unnamed: J18.1, U2.8
unnamed: J19.1, U2.12
unnamed: L1.1, R30.2, U7.3
unnamed: L2.1, P2.2, R30.1
unnamed: R2.2, U3.41
unnamed: R5.2, U3.39
unnamed: R6.2, U3.40
unnamed: R8.2, U3.30
unnamed: R9.2, R10.2, U3.29
unnamed: R12.2, U1.8
unnamed: R16.2, R21.1, U1.7
unnamed: R20.1, U6.8
unnamed: R22.2, R23.1, U6.7
unnamed: R27.1, U2.26
unnamed: R28.1, U2.27
unnamed: R29.1, U2.28
unnamed: SW1.2, U2.7
unnamed: SW2.1, U2.29
unnamed: U3.42, U4.5
OLED_CS: J7.7, U2.24
OLED_D/C: J7.6, U2.22
OLED_RESET: J7.5, U2.23
PM_SCK: J7.3, J16.5, U2.55
PM_SDI: J16.3, U2.57
PM_SDO: J7.4, J16.4, U2.56
PM_SS: J16.2, U2.54
RI: U2.2, U3.34
Rx: J10.1, J20.2, U2.52
SWD_CLK: J20.5, U2.49
SWD_DIO: J20.1, U2.46
Tx: J9.1, J20.4, U2.51
UART_GPS_RX: J17.8, U2.17, U7.10
UART_GPS_TX: J17.7, U2.16, U7.9
USART_debug_rx: J17.14, U2.59
USART_debug_tx: J17.13, U2.58
WIRELESS_reset: J17.10, J21.1, U2.53, U3.15
gps_fix: J17.9, R1.1, U2.15, U7.13
gps_pulses: J17.4, U2.10, U7.6
gps_reset: J17.5, U2.11, U7.7
gps_standby: J17.6, U2.14, U7.8
i2c_scl: J8.2, R3.2, U2.34, U8.6
i2c_sda: J8.1, R4.2, U2.35, U8.5

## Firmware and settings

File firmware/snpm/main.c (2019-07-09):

/*
 * This file is part of the SenoricNet project, https://sensoricnet.cz
 *
 * Copyright (C) 2017 Pavel Polach <ivanahepjuk@gmail.com>
 *
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
 * You should have received a copy of the GNU Lesser General Public License
 * along with this library.  If not, see <http://www.gnu.org/licenses/>.
 */

#include "main.h"

//debug
int cykly = 0;
char cykly_str[10];

int frame_counter = 0;

/* For semihosting on newlib */
//extern void initialise_monitor_handles(void);

//Global variables for burst register reading, bme280
int32_t t_fine;
uint8_t comp_data[26];	//used for readings of compensation data
uint8_t burst_read_data[8] = {0};	//in loop measured data readed into this

// gps global variables
char gps_rx_buffer[255] = {0};
uint8_t gps_rx_buffer_pointer = 0;
char gps_utc_time[10] = {0};
char gps_latitude[9] = {0};
char gps_latitude_ns[1] = {0};
char gps_longitude[10] = {0};
char gps_longitude_ew[1] = {0};
char gps_quality_indicator[1] = {0};
char gps_altitude[8] = {0};
float wgs_latitude = 0.0;
float wgs_longitude = 0.0;
float altitude = 0.0;

// measured values
float temp = 0;
float press = 0;
float hum = 0;
float pm1 = 0;
float pm2_5 = 0;
float pm10 = 0;

//nbiot BC-95 signal data //signal strength, bit error rate
int csq[2] = {0}; //signal strength, bit error rate
int nuestats[14] = {0}; //signal power, total power, tx power, tx time, rx time, cell ID, DL MCS, UL MCS, DCI MCS, ECL, SNR, EARFCN, PCI, RSRQ


// Global variables for compensation functions, bme280:
// temperature
uint16_t dig_T1;
int16_t dig_T2, dig_T3;
// pressure
uint16_t dig_P1;
int16_t dig_P2, dig_P3, dig_P4, dig_P5, dig_P6, dig_P7, dig_P8, dig_P9;
// humidity
uint8_t dig_H1, dig_H3;
int16_t dig_H2, dig_H4, dig_H5;
int8_t dig_H6;

// dev_id
char ID[11] = {DEV_ID};
char id_decoded[23]={0};

// Global variables for burst register reading, for OPC-N2
uint8_t histogram_buffer[62];	//whole dataset of opc readed into this
uint8_t pm_values_buffer[12] = {0};	//only pm data





/********************************************************************************************
 *
 * MAIN
 *
 ********************************************************************************************/


int main(void)
{
  clock_setup();
  //systick_setup(250);//250ms tick = 500ms period = 2Hz
//  moje_iwdg_setup();
  gpio_setup();
//  usart_setup();
  i2c_setup();

while(1) {
led_flash(3, 3, 20000);
  //BME280_init();
  atecWake();
  atec();
  wait(2000000);
}
  moje_iwdg_reset();

  wait(SEC*3);
  gpio_set(GPIOD, GPIO2); //SS Log 1
  gpio_clear(GPIOD, GPIO2); //SS Log 0
  gpio_set(GPIOD, GPIO2); //SS Log 1

  debug_usart_send("Welcome to SensoricNet particlemeter");
  #if DEVICE_TYPE == NBIOT
    debug_usart_send("device type is NBIoT");
  #endif
  moje_iwdg_reset();
  particlemeter_power_cycle();
  spi_setup();
  debug_usart_send("tady");
  #if BME280 == 1
    BME280_init();
  #endif
  led_flash(1, 3, 20000);
  nbiot_reset();
  led_flash(1, 3, 200000);
	// semihosting - stdio po debug konzoli, inicializace
	/*
	#if defined(ENABLE_SEMIHOSTING) && (ENABLE_SEMIHOSTING)
		initialise_monitor_handles();
		setbuf(stdout, NULL);
	#endif
	*/
  struct CayenneLPP *lpp;
  unsigned char *buf;
  int size;

  usart_disable_rx_interrupt(USART2);
  usart_disable(USART2);

  //Connect to nbiot network
  #if DEVICE_TYPE == NBIOT
    wait(SEC*1); //until quectel wakes up
    //usartSend("test uvnitr\r\n", 2);
    debug_usart_send("NBIoT site connect");
    moje_iwdg_reset();
    nbiot_connect();
    led_flash(1, 3, 20000);
    moje_iwdg_reset();
    send_reboot_variable();
  #endif

  //Connect to lora network
  #if DEVICE_TYPE == LORAWAN
    debug_usart_send("rn2483 reset");
    lorawan_reset();
    debug_usart_send("lora connect");
    lorawan_connect();
    debug_usart_send("lora connected");
  #endif

  #if PARTICLEMETER == 1
    moje_iwdg_reset();
    debug_usart_send("PM switching on");
    particlemeter_ON();
    particlemeter_set_fan(FAN_SPEED);
    wait(SEC * 1);
    debug_usart_send("PM switched on");
    read_pm_values();
    wait(SEC *5);
    debug_usart_send("PM cleared");
  #endif
  moje_iwdg_reset();

	// init cayenne lpp
  lpp = CayenneLPP__create(255);

  //flash(3, 100000);
  while (1) {
    debug_usart_send("New loop");
    moje_iwdg_reset();

    //vycitani statistik site a ukladani do poli csq a nuestats
    while(nbiot_csq())
      wait(SEC*2);
    while(nbiot_nuestats())
      wait(SEC*2);

    // readout particlemeter data
    #if PARTICLEMETER == 1
      read_pm_values();
    #endif

    #if BME280 == 1
      // readout BME data
      BME280_data_readout(burst_read_data);
    #endif
    // debug gps
    char tmp_string[200] = {0};
    int w;

    for (w=0; w<100; w++) {
      if (gps_rx_buffer[w] != '\n') {
        tmp_string[w] = gps_rx_buffer[w];
      }
    }
    debug_usart_send(tmp_string);

    char pointer_debug_string[80] = {0};
    sprintf(pointer_debug_string, "pointer %d", gps_rx_buffer_pointer);
    debug_usart_send(pointer_debug_string);

    sprintf(pointer_debug_string, "time: %s, latitude: %s, longitude: %s, altitude: %s, fix: %s", gps_utc_time, gps_latitude, gps_longitude, gps_altitude, gps_quality_indicator);
    debug_usart_send(pointer_debug_string);

    // testovaci hodnoty natvrdo, jinak gps_latitude, gps_longitude
//			wgs_latitude = convert_gps_to_wgs84_latitude("5133.82");
//			wgs_longitude = convert_gps_to_wgs84_longitude("00042.24");
    wgs_latitude = convert_gps_to_wgs84_latitude(gps_latitude);
    wgs_longitude = convert_gps_to_wgs84_longitude(gps_longitude);
    // atof neni bezpecne, TODO
    altitude = atof(gps_altitude);

    if (gps_quality_indicator[0] != '0') {
      sprintf(pointer_debug_string, "wgs latitude: %f, wgs longitude: %f, altitude: %f", wgs_latitude, wgs_longitude, altitude);
      debug_usart_send(pointer_debug_string);
    }

    temp = BME280_temp();
    press = BME280_press();
    hum = BME280_hum();
    #if PARTICLEMETER == 1
      pm1 = particlemeter_pm1();
      pm2_5 = particlemeter_pm2_5();
      pm10 = particlemeter_pm10();
    #endif

    debug_usart_send("Encode values");
    char debug_data_string[150] = {0};
    sprintf(debug_data_string, "hum: %.2f, temp: %.2f, press: %.2f, pm1: %.2f, pm2_5: %.2f, pm10: %.2f", hum, temp, press, pm1, pm2_5, pm10);
    debug_usart_send(debug_data_string);
		
    CayenneLPP__addTemperature(lpp, 1, temp-2.1); //FIXME PRASARNA
    CayenneLPP__addBarometricPressure(lpp, 2, press);
    CayenneLPP__addRelativeHumidity(lpp, 3, hum);
    #if PARTICLEMETER == 1
      CayenneLPP__addAnalogInput(lpp, 4, pm1);
      CayenneLPP__addAnalogInput(lpp, 5, pm2_5);
      CayenneLPP__addAnalogInput(lpp, 6, pm10);
    #endif

		// jsou udaje gps validni, pripadne zmenily se od minula? TODO
    if (gps_quality_indicator[0] != '0') {
      CayenneLPP__addGPS(lpp, 7, wgs_latitude, wgs_longitude, altitude);
    }
		
		//statistiky site

    CayenneLPP__addDigitalInput(lpp, 8, csq[0]);//signal strength - jeste se da prepocitat podle datasheetu
    CayenneLPP__addDigitalInput(lpp, 9, csq[1]);//channel bit error rate
    CayenneLPP__addAnalogInput(lpp, 10, nuestats[0]);//signal power
    CayenneLPP__addAnalogInput(lpp, 11, nuestats[1]);//total power
    CayenneLPP__addAnalogInput(lpp, 12, nuestats[2]);//tx power
    CayenneLPP__addAnalogInput(lpp, 13, nuestats[3]);//tx time
    CayenneLPP__addAnalogInput(lpp, 14, nuestats[4]);//rx time
								//cell id
    CayenneLPP__addAnalogInput(lpp, 11, nuestats[6]);//DL MCS
    CayenneLPP__addAnalogInput(lpp, 11, nuestats[7]);//UL MCS
    CayenneLPP__addAnalogInput(lpp, 11, nuestats[8]);//DCI MCS
    CayenneLPP__addAnalogInput(lpp, 11, nuestats[9]);//ECL
    CayenneLPP__addAnalogInput(lpp, 11, nuestats[10]);//SNR
    CayenneLPP__addAnalogInput(lpp, 11, nuestats[11]);//EARFCN
    CayenneLPP__addAnalogInput(lpp, 11, nuestats[12]);//PCI
    CayenneLPP__addAnalogInput(lpp, 11, nuestats[13]);//RSRQ

    buf=CayenneLPP__getBuffer(lpp);
    size=CayenneLPP__getSize(lpp);

		// Send it off
		//sendData(CayenneLPP__getBuffer(lpp), CayenneLPP__getSize(lpp));
		//printf("Encoded data size: %i\n", size);

    char hex_string[400] = {0};		//encoded string here
    char send_string[400] = {0};	//string to send here
		
		//ascii-hex encoding is happening here:
    int j = 0;
    char znak[3];
		
    while(j<size){
      charToHex(buf[j], znak);
      strcat(hex_string, znak);
      j++;
    }
		

    #if DEVICE_TYPE == LORAWAN
    //sestaveni stringu pro LORAWAN
    strcat(send_string, "mac tx uncnf 1 ");
    strcat(send_string, hex_string);

    //odeslani stringu, checkuje "ok", pokud nedostane ok tak to zkusi za chvili znova
    while(lorawan_sendCommand(send_string, "ok", 1)) {
      // TODO odstupnovat, nekolik pokusu, reset (nebo aspon connect)
      wait(SEC*3);
    }

    frame_counter++;

		// jednou za 8 frejmu uloz frame counter
    if ((frame_counter & 0x07) == 0) {
      lorawan_mac_save();
    }
    #endif

		
    #if DEVICE_TYPE == NBIOT
    //tady se konvertuje na string a ulozi delka payloadu (int)

    char nbiot_data_length[10];
    sprintf (nbiot_data_length, "%d", size+(11));

    //sestaveni stringu pro Nb-IOT
    strcat(send_string, "AT+NSOST=0,193.84.207.60,9999,");
    strcat(send_string, nbiot_data_length);
    strcat(send_string, ",");

    ////experimental, eeprom string decoding
    j=0;
    while(j<10){
      charToHex(ID[j], znak);
      strcat(id_decoded, znak);
      j++;
    }
    id_decoded[20] = '0';
    id_decoded[21] = '0';
    id_decoded[22] = 0x00; //=NULL

    usartSend(id_decoded, 2);

    strcat(send_string, id_decoded);	//nbiot-0001
    //strcat(send_string, "00");	//nbiot-0001
    strcat(send_string, hex_string);
    strcat(send_string, "\r\n");
		
    //socket opening
    while (nbiot_sendCommand("AT+NSOCR=DGRAM,17,9999,1\r\n", "OK\r\n", 4))
      wait(SEC*1);
    //Sending datagram
    usartSend(send_string, 2);
    while (nbiot_sendCommand(send_string, "OK", 4))
      wait(SEC*3);
    //Closing socket
    while (nbiot_sendCommand("AT+NSOCL=0\r\n", "OK", 2))
      wait(SEC*1);
    #endif

		
    CayenneLPP__reset(lpp);
    //lpp->cursor = NULL;
		

    char loop_debug_string[20] = {0};
    sprintf(loop_debug_string, "Loop %d done", cykly);
    debug_usart_send(loop_debug_string);

    cykly++;

    flash(2, 100000);

		/*
//pm zeros restart check here?
		*/
    moje_iwdg_reset();
    usart_enable_rx_interrupt(USART2);
    usart_enable(USART2);
		
    wait(SEC *14);
    usart_disable_rx_interrupt(USART2);
    usart_disable(USART2);
		
    }
  return 0;
}

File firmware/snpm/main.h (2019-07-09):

#ifndef MAIN_H
#define MAIN_H

#include <libopencm3/stm32/spi.h>
#include <stdio.h>
#include <stdlib.h>
#include <string.h>
#include <libopencm3/stm32/f0/nvic.h>
#include "inc/functions.h"
#include "inc/bme280.h"
#include "inc/opcn2.h"
#include "inc/wireless.h"
#include "inc/cayenne_lpp.h"
#include "inc/iwdg.h"
#include "m24c04.h"


#include <libopencm3/stm32/rcc.h>
#include <libopencm3/stm32/gpio.h>
#include <libopencm3/cm3/systick.h>
#include <libopencm3/stm32/iwdg.h>

//how long it waits at the end of each loop?
#define WAIT 50

//USART1 is used as debug output, if defined, debug output is send
#define DEBUG
#define DEBUG_USART USART1
#define DEBUG_BAUDRATE 57600

//define which hw we have connected
#define PARTICLEMETER 0
#define BME280 0

// define macro for device type description
#define NBIOT 1
#define LORAWAN 2

// define pins for peripherals

// leds
#define LED1_GPIO_GROUP GPIOB
#define LED1_GPIO GPIO0
#define LED2_GPIO_GROUP GPIOB
#define LED2_GPIO GPIO1
#define LED3_GPIO_GROUP GPIOB
#define LED3_GPIO GPIO2

// IoT module reset
#define IOT_RESET_GPIO_GROUP GPIOC
#define IOT_RESET_GPIO GPIO12


// u techto promennych se predpoklada jejich naplneni z cmdline

//Choose your platform here
#ifndef DEVICE_TYPE
#define DEVICE_TYPE NBIOT
#endif

#ifndef LORAWAN_DEVEUI
#define LORAWAN_DEVEUI "0011223344556677"
#endif

#ifndef LORAWAN_APPEUI
#define LORAWAN_APPEUI "0011223344556677"
#endif

#ifndef LORAWAN_APPKEY
#define LORAWAN_APPKEY "00112233445566778899aabbccddeeff"
#endif

// dulezite pouze pro nbiot
#ifndef DEV_ID
#define DEV_ID "nbiot-test"
#endif

#if DEVICE_TYPE == LORAWAN
#define USART_BAUDRATE 57600
#define LORA_USART (USART4)
#endif

#if DEVICE_TYPE == NBIOT
#define USART_BAUDRATE 9600
#endif


#endif

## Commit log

2018-01-02 This is the first official commit to the SensoricNet particle meter repository. In the past, there were more repositories and it was a bit chaotic, but from now there will be only one, both for fW an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
    [BOM.ods, Microchip_RN2483_LORAWAN_module.kicad_pcb, Microchip_RN2483_LORAWAN_module.sch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]
2018-01-22 opc-n2 improved booting stability
    [functions.c, main.c, opcn2.c]
2018-02-05 spi problems
2018-02-05 spi stable, commit before cleaning
2018-02-06 SPI working, compilation errors cleaned, measured data are going out to USART4
    [bme280.c, functions.c, main.c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]
2018-02-07 code refactorization
    [BOM.ods, Microchip_RN2483_LORAWAN_module.kicad_pcb, Microchip_RN2483_LORAWAN_module.sch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]
2018-02-07 folders juggling
    [BOM.ods, Microchip_RN2483_LORAWAN_module.kicad_pcb, Microchip_RN2483_LORAWAN_module.sch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]
2018-03-06 pred tim nez to cele rozvrtam abych prisel na to kde je problem s opcn2
    [main.c, opcn2.c]
2018-03-21 memory leak asi opraveny
    [cayenne_lpp.h, functions.c, main.c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]
2018-03-21 Nb-IOT i LORAWAN ready na test stability, pridan main.h s konfiguracnima definama, uklizeno v ramci moznosti
    [functions.c, main.c, main.h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]
2018-04-11 uklid kodu, lora zase funkcni, pridan provisioning z csv souboru
    [sensoricnet_lora_ids_example.csv]
2018-04-12 lora: oprava datarate, prubezne ukladani frame counteru
2018-04-13 pokus dale ucesat kod, ale nejak se mi to ted seka a nemam u sebe debug. tento commit nemergeovat!
    [sensoricnet_lora_ids_example.csv]
2018-04-15 pokus o uchozeni mereni relativni vlhkosti. zkontroloval jsem kompenzacni matematiku a nevidim tam problem, relativni vlhkost to uz meri, ale se zapornym znamenkem, coz zjevne neni ok. TODO
    [bme280.c, main.c]
2018-05-02 usart 4 na wireless mi funguje preruseni, tzn kdyz do patice od wireless pripojim ftdi externi adapter, tak cokoliv v terminalu napisu, snpm mi vrati zpet.
2018-05-02 interrupt predelany na USART2, ale neotestovany, protoze na vyvojove desce je USART2 pristupny po odpajeni jumperu
2018-07-13 nbiot preroutovany
    [BOM.ods, sensenet_particlemeter.csv, sensenet_particlemeter.kicad_pcb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]
2018-07-13 nbiot preroutovany 2
    [sensenet_particlemeter.sch]
2018-07-14 Zaklad nove verze je hotovy, ted jdu udelat vetsi zmeny v napajeni a layoutu, priprava na shield atd.
    [sensenet_particlemeter.kicad_pcb, sensenet_particlemeter.sch]
2018-07-14 Novy rozmer desky, zmena napajeni z LDO na step down, pridany 1000uF na 5V
    [sensenet_particlemeter.kicad_pcb, sensenet_particlemeter.sch]
2018-07-17 zonglovani zase s gitem
    [BOM.ods, sensenet_particlemeter.csv, sensenet_particlemeter.kicad_pcb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]
2018-07-18 objednavam prototypy
    [sensenet_particlemeter.kicad_pcb, sensenet_particlemeter.sch]
2018-07-19 pridana kompilace gps souradnic z csv jako workaround nefunkcni gps
    [sensoricnet_lora_ids_example.csv]
2018-07-30 pred debugem noveho hardwaru
    [sensenet_particlemeter.csv, sensenet_particlemeter.kicad_pcb, sensenet_particlemeter.ods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]
2018-08-04 modifikace led diod v hw verzi 2
2018-08-08 redefinice led, inicializace USART1 pro debug vystupy, debug fce
2018-09-06 Startovaci bod pro praci na hw 2.0
    [sensenet_particlemeter.sch]
2018-09-07 poresene preruseni pri cteni z SPI
2018-09-24 pred displayem
    [sensenet_particlemeter.kicad_pcb, sensenet_particlemeter.sch]
2018-10-16 novy hw
    [_saved_sensenet_particlemeter.sch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]
2018-11-20 snazim se rozchodit novou serii, jebne me z toho z chvili
    [BOMnjhgjhgjhgkgj.ods, _saved_sensenet_particlemeter.sch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]
2018-11-21 novy hw FLASHABLE, watchdog resi spoustu problemu:)
    [functions.c, main.c, wireless.c]
2018-11-28 5 sensoru flashnuto, stability check
    [wireless.c]
2018-11-30 pridani reboot signau, opraveni pullupu u particlemeteru
    [functions.c, main.c, opcn2.c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]
2018-12-04 problemy s cpol cpha, pokus o stabilni fw
    [functions.c, main.c, opcn2.c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]
2018-12-05 posila casteji, pokus o odstraneni rebootu
    [functions.c, main.c, main.h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]
2019-01-25 zonglovani s repama
    [sensenet_particlemeter-2019-01-10-13-48-53.sch, sensenet_particlemeter-2019-01-23-12-09-05.sch, sensenet_particlemeter.sch]
2019-02-12 rozdelane upravicky
    [sensenet_particlemeter.kicad_pcb, sensenet_particlemeter.sch]
2019-02-13 dalsi updaty
    [_saved_sensenet_particlemeter.sch, sensenet_particlemeter.kicad_pcb, sensenet_particlemeter.sch]
2019-02-14 Daily update, rework zdroju - oba dva LDO s adjustem, 5Venable, pico clasp connector, priprava na lorawan shield
    [sensenet_particlemeter.kicad_pcb, sensenet_particlemeter.sch]
2019-02-15 daily, jeste musim prehodit gps doprava
    [sensenet_particlemeter.kicad_pcb]
2019-02-19 finalizing nbiot
    [sensenet_particlemeter.kicad_pcb]
2019-02-19 VELKY UKLID
    [BOM.csv, BOM.ods, BOMnjhgjhgjhgkgj.ods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]
2019-02-19 artwork, aligning, checking, polishing..
    [sensenet_particlemeter.kicad_pcb, sensenet_particlemeter.sch]
2019-02-20 SENSORICNET mother board v.: 1.0
    [sensenet_particlemeter.kicad_pcb, sensenet_particlemeter.sch]
2019-02-20 priprava FAB data
    [BOM.ods, sensenet_particlemeter.csv, sensenet_particlemeter.kicad_pcb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]
2019-02-25 shield template added
    [sensenet_particlemeter.kicad_pcb, sensenet_particlemeter.sch, sensoricnet_shield..kicad_pcb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]
2019-02-25 LORAWAN shield 1.0 added
    [sensoricnet_shield..kicad_pcb, sensoricnet_shield..sch, sensoricnet_shield.kicad_pcb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]
2019-03-07 verze 1.0 manufacture files
    [_saved_sensenet_particlemeter.sch, sensenet_particlemeter.csv, sensenet_particlemeter.ods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]
2019-03-07 verze 1.0 manufacture files + pictures, readme.MD
    [_saved_sensenet_particlemeter.sch]
2019-05-05 gerbers added
    [sensenet_particlemeter-B.Cu.gbr, sensenet_particlemeter-B.Mask.gbr, sensenet_particlemeter-B.Paste.gbr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]
2019-07-09 lorawan gerbers
    [sensoricnet_shield-B.Cu.gbr, sensoricnet_shield-B.Mask.gbr, sensoricnet_shield-B.Paste.gbr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]
2019-07-10 lorawan schematics added

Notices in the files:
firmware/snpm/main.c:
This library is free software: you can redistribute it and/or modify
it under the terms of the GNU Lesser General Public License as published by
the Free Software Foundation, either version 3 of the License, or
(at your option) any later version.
